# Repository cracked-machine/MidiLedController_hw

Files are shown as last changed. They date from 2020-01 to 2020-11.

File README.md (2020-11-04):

# MIDI LED Controller (HW)

Required Kicad Hardware library: https://github.com/cracked-machine/KicadLibrary

For the corresponding SW repository:
[MidiLedController_sw](https://github.com/cracked-machine/MidiLedController_sw)

## Detailed Specifications:

Power Supply: 12V @ 2A (center positive).
Total quiescent current consumption: 85mA
Voltage output per channel: 10V
Current output per channel (Nom.): 
Total current consumption (Nom.): 
Current output per channel (fault limit): 
Total current consumption (fault limit): 2A

 ## Theory of Operation

 ### Power Supply overview

 A 12V DC input supply is stepped-down to 10V. Most of this will be used to power the LEDs. This is regulated down to provide 5V @ 100mA for the status leds. Additionally 3.3V @ 20mA is provided to the microcontroller.

<p align="center">

</p>

### Output Channel overview

 MIDI Note-On commands are received and synchronised with the gating of 9 independant LED output channels.
 The brightness of all 9 channels can be adjusted simultaneously at the rear of the module.

 Fault protection monitors each output channel for short-circuit and over-current conditions.
 Fault protection is done on the _high side_ of the switch. MIDI data transmission is done on the _low side_ of the switch. i.e. the output channel anode remains at 5V (during normal operation) while the cathode is toggled by the Microcontroller GPIO.

 Individual output channel status is indicated with a tricolour LED.  See details on the Status LED sub-system below.

<p align="center">

</p>

### Output channel status LED statemachine

Each output channel has a tricolour LED. As before a _green_ LED indicates that a load is connected to the output channel and power delivery to that channel is functioning as normal. An overcurrent or short circuit event is indicated by a _red_ LED and all power is disabled from that output channel.

A _blue_ LED indicates that no load is connected to the output channel. At this point, if MIDI data is still being transferred to that channel, the status LED will alternate between green and blue, in sync with the received MIDI data. This allows testing of the MIDI data transmission without needing to connect a load to the output channel.

When the load is connected, the status LED will **always** remain solid _green_.

A _red_ power fault status such as over current or short circuit will **always** override the other status colours.

<p align="center">

</p>

### TODO

* upgrade SMPS to drop-in 3A components (TP56339, TPS54302, TPS54309). Considerations are Fsw/L1 size, Thermal Limits and cooling.
* Upgrade output series SOT23 transistor to higher currrent/thermal limit component...or to larger component (SOT223?)
* Test audio input triggering
* Additional pot control for reset delay (dual gang/ concetric pot)
* Upgrade DIP4 to DIP6

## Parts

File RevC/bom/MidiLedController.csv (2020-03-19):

Reference | Quantity | Value | Footprint | Datasheet | EbayPurchase | MouserNo | Type | LcscNo | RsComponentsNo | Unit Cost | Drawing
C1 C4 | 2 | 10u | Capacitor_SMD:C_1206_3216Metric_Pad1.42x1.75mm_HandSolder | ~ |  | 81-GRM21BC81C106KE5L | 25V | C14860 |  | 0.030736
C11 C12 | 2 | 22uF | Capacitor_SMD:C_1206_3216Metric_Pad1.42x1.75mm_HandSolder | ~ |  |  | X7R 25V | C268007 |  | 0.073018
C2 | 1 | 330nF | Capacitor_SMD:C_1206_3216Metric_Pad1.42x1.75mm_HandSolder | ~ |  |  | 25V | C73142 |  | 0.011209
C26 C5 | 2 | 100pF | Capacitor_SMD:C_0805_2012Metric_Pad1.15x1.40mm_HandSolder | ~ |  |  | N/A | C152892 |  | 0.008889
C3 | 1 | 100nF | Capacitor_SMD:C_1206_3216Metric_Pad1.42x1.75mm_HandSolder | ~ |  |  | 10V | C94108 |  | 0.005
C30 | 1 | 100n | Resistor_SMD:R_0805_2012Metric_Pad1.15x1.40mm_HandSolder | ~ |  |  | 10V | C94108 |  | 0.005
C32 | 1 | 4.7u | Capacitor_SMD:C_0805_2012Metric_Pad1.15x1.40mm_HandSolder | ~ |  |  | N/A | C87998 |  | 0.020584
C33 | 1 | 10n | Capacitor_SMD:C_0805_2012Metric_Pad1.15x1.40mm_HandSolder | ~ |  |  | N/A | C107135 |  | 0.009327
C34 C29 C31 | 3 | 1u | Capacitor_SMD:C_0805_2012Metric_Pad1.15x1.40mm_HandSolder | ~ |  |  | N/A | C376927 |  | 0.009595
C6 C28 | 2 | 100n | Capacitor_SMD:C_0805_2012Metric_Pad1.15x1.40mm_HandSolder | ~ |  |  | N/A | C94108 |  | 0.005
C8 | 1 | 180pF | Resistor_SMD:R_0805_2012Metric_Pad1.15x1.40mm_HandSolder | ~ |  |  | N/A | C152881 |  | 0.003814
C9 | 1 | 100nF | Resistor_SMD:R_0805_2012Metric_Pad1.15x1.40mm_HandSolder | ~ |  |  | X7R | C94108 |  | 0.005
D13 | 1 | BZT52C5V1 | Diode_SMD:D_SOD-123 | https://diotec.com/tl_files/diotec/files/pdf/datasheets/bzt52b2v4.pdf |  |  | Vz=5.1V | C353516 |  | 0.005325
D2 | 1 | 1N4148 | Diode_SMD:D_SOD-323_HandSoldering | ~ |  |  | N/A | C110221 |  | 0.004722
D_STATUS1 D_STATUS_2 D_STATUS_3 D_STATUS_4 D_STATUS_5 D_STATUS_6 D_STATUS_7 D_STATUS_8 D_STATUS_9 | 9 | LED_RAGB | LED_THT:LED_D5.0mm-4_RGB_Wide_Pins | ~ | TRUE |  |  |  |  | 0.11
J1 | 1 | Molex 2Way KK254 | Connector_PinHeader_2.54mm:PinHeader_1x05_P2.54mm_Vertical | ~ | TRUE
J12 | 1 | Barrel_Jack | Connector_BarrelJack:BarrelJack_Horizontal | ~ | TRUE |  |  |  |  | 0.04
J_AUX1 | 1 | Conn_01x04 | Connector_PinHeader_2.54mm:PinHeader_1x04_P2.54mm_Vertical | ~ | TRUE
J_MIDI_IN1 | 1 | DIN-5 | custom_sockets:RS_5P180_DIN5_SOCKET_WSHIELD | https://docs-emea.rs-online.com/webdocs/1579/0900766b81579be1.pdf | TRUE |  |  |  |  | 0.23 | https://docs-emea.rs-online.com/webdocs/1579/0900766b81579be0.pdf
J_OUT1 J_OUT2 J_OUT3 J_OUT4 J_OUT5 J_OUT6 J_OUT7 J_OUT8 J_OUT9 | 9 | Barrel_Jack_Switch | Connector_BarrelJack:BarrelJack_Horizontal | ~ | TRUE |  |  |  |  | 0.04
L2 | 1 | 4.7uH | Inductor_SMD:L_Taiyo-Yuden_NR-80xx_HandSoldering | https://www.mouser.co.uk/datasheet/2/396/wound04_e-1290968.pdf |  |  | 3A | C266428 |  | 0.054256
Q1 Q2 Q3 Q4 Q5 Q6 Q7 Q8 Q9 Q10 Q11 Q12 Q13 Q14 Q15 Q16 Q17 Q18 | 18 | MBT3946DW1T1 | Package_TO_SOT_SMD:SOT-363_SC-70-6 | http://www.onsemi.com/pub_link/Collateral/MBT3946DW1T1-D.PDF |  |  |  |  | 791-6078 | 0.045
Q21 | 1 | HX2301A | Package_TO_SOT_SMD:SOT-23 | https://datasheet.lcsc.com/szlcsc/1912111437_HX-hengjiaxing-HX2301A_C296298.pdf |  |  | VGS=+/-12V | C296298 |  | 0.01
QLOAD1 QLOAD2 QLOAD3 QLOAD4 QLOAD6 QLOAD7 QLOAD8 QLOAD9 QLOAD5 | 9 | MMBT3904 | Package_TO_SOT_SMD:SOT-23 | https://datasheet.lcsc.com/szlcsc/1810202112_Guangdong-Hottech-MMBT3904_C181119.pdf |  |  |  | C20526 |  | 0.009
R1 R3 R2 R6 R5 R8 R7 R11 R10 R14 R12 R18 R17 R20 R19 R22 R21 R24 R23 | 19 | 10K | Resistor_SMD:R_0805_2012Metric_Pad1.15x1.40mm_HandSolder | ~ |  |  | N/A | C115295 |  | 0.001482
R119 R120 R121 R122 | 4 | 1K | Resistor_SMD:R_0805_2012Metric_Pad1.15x1.40mm_HandSolder | ~ |  |  | N/A | C25623 |  | 0.001
R15 R13 | 2 | 100K | Resistor_SMD:R_0805_2012Metric_Pad1.15x1.40mm_HandSolder | ~ |  |  | N/A | C118844 |  | 0.001534
R16 | 1 | 6K2 | Resistor_SMD:R_0805_2012Metric_Pad1.15x1.40mm_HandSolder | ~ |  | 71-CRCW080510K0FKEAC | N/A |  |  | 0.046
R4 | 1 | 220R | Resistor_SMD:R_0805_2012Metric_Pad1.15x1.40mm_HandSolder | ~ |  | 71-CRCW0805220RFKEAC | N/A |  |  | 0.046
R74 R25 | 2 | 100R | Resistor_SMD:R_0805_2012Metric_Pad1.15x1.40mm_HandSolder | ~ |  |  | N/A | C106949 |  | 0.001048
R86 | 1 | 100K | Resistor_SMD:R_1206_3216Metric_Pad1.42x1.75mm_HandSolder | ~ |  |  | N/A | C118844 |  | 0.001534
R9 | 1 | 4K7 | Resistor_SMD:R_0805_2012Metric_Pad1.15x1.40mm_HandSolder | ~ |  | 279-CRGP0805F270R | N/A |  |  | 0.13
RV1 | 1 | PTH901 | PTH901:PTH901 | https://www.bourns.com/docs/product-datasheets/PTH90.pdf |  | 652-PTH901-030S-103B | PTH901-030S-103B1 |  |  | 1.30
SW1 | 1 | SW_DIP_x04 | Button_Switch_THT:SW_DIP_SPSTx04_Slide_6.7x11.72mm_W7.62mm_P2.54mm_LowProfile | ~ | TRUE |  |  |  |  | 0.07
SW2 | 1 | SW_SPST | Button_Switch_THT:SW_Tactile_SPST_Angled_PTS645Vx31-2LFS | ~ | TRUE |  |  |  |  | 0.06
TP4 TP1 TP7 TP50 TP46 TP44 TP42 TP19 TP3 TP28 TP31 TP30 TP2 | 13 | TestPoint | TestPoint:TestPoint_Pad_1.0x1.0mm | ~ |  |  |  |  |  | ———
U1 U2 U3 U4 U5 U6 U7 U8 U9 U10 U11 U12 U13 U14 U15 U16 U17 U18 | 18 | RAx4_4 1K | Resistor_SMD:R_Array_Convex_4x0603 | https://datasheet.lcsc.com/szlcsc/1912111437_HX-hengjiaxing-HX2301A_C296298.pdf |  |  | N/A | C396839 |  | 0.006
U20 | 1 | STM32F051K8Tx | Package_QFP:LQFP-32_7x7mm_P0.8mm | http://www.st.com/st-web-ui/static/active/en/resource/technical/document/datasheet/DM00039193.pdf |  | 511-STM32F051K8T6 |  |  |  | 1.81
U21 | 1 | 6N135S | Package_DIP:DIP-8_W8.89mm_SMDSocket_LongPads | https://optoelectronics.liteon.com/upload/download/DS70-2008-0032/6N135-L%206N136-L%20series.pdf |  | 859-6N135S |  |  |  | 0.42
U22 | 1 | TPS54202DDCR | Package_TO_SOT_SMD:SOT-23-6 | http://www.ti.com/lit/ds/symlink/tps54202.pdf |  |  |  | C191884 |  | 0.14
U23 | 1 | L7805 | Package_TO_SOT_SMD:TO-263-2 | http://www.st.com/content/ccc/resource/technical/document/datasheet/41/4f/b3/b0/12/d4/47/88/CD00000444.pdf/files/CD00000444.pdf/jcr:content/translations/en.CD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 |  |  |  | C15077 |  | 0.17
U24 | 1 | MCP1754ST-3302E/CB | Package_TO_SOT_SMD:SOT-23 | http://ww1.microchip.com/downloads/en/DeviceDoc/20002276C.pdf |  | 579-MCP1754T-3302ECB |  |  |  | 0.26
U25 | 1 | NCP51460SN33T1G | Package_TO_SOT_SMD:SOT-23 | https://www.onsemi.com/pub/Collateral/NCP51460-D.PDF |  | 863-NCP51460SN33T1G | Voltage Reference |  |  | 0.34
U_LOAD1 U_LOAD2 U_LOAD3 U_LOAD4 U_LOAD5 U_LOAD6 U_LOAD7 U_LOAD8 U_LOAD9 | 9 | NCV8450 | Package_TO_SOT_SMD:SOT-223-3_TabPin2 | https://datasheet.lcsc.com/szlcsc/1912111437_ON-Semiconductor-NCV8450ASTT3G_C100028.pdf |  |  |  | C100028 |  | 0.26
TOTAL |  |  |  |  |  |  |  |  |  | 5.800073

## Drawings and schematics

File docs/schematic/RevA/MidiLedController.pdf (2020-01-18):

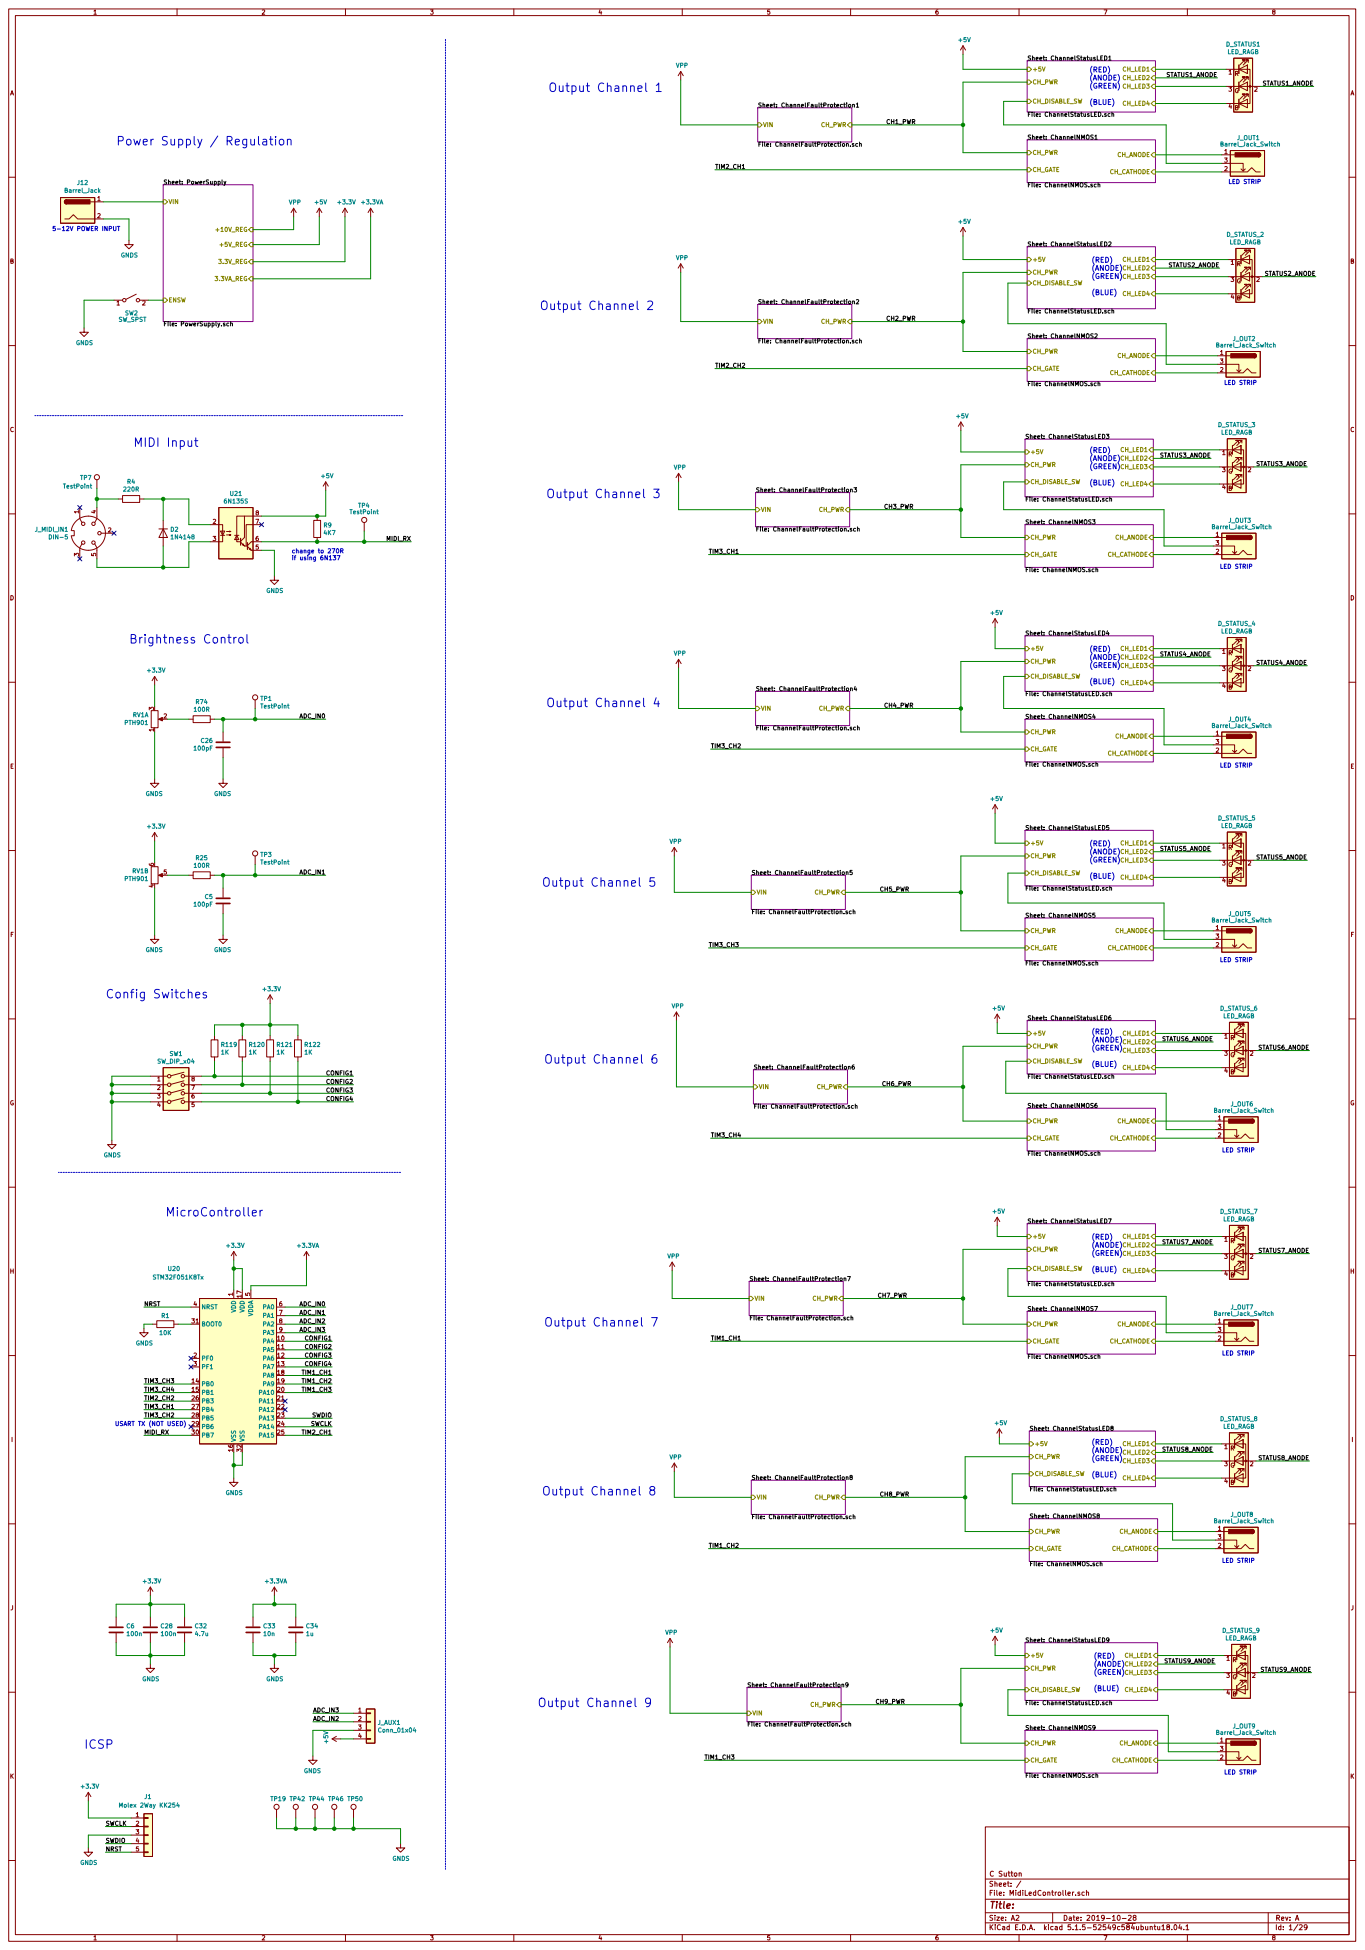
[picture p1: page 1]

File: PowerSupply.sch VIN

Sheet: ChannelNMOS1 File: ChannelNMOS.sch CH_PWR

Sheet: ChannelNMOS2 File: ChannelNMOS.sch CH_PWR

Sheet: ChannelNMOS3 File: ChannelNMOS.sch CH_PWR

Sheet: ChannelNMOS4 File: ChannelNMOS.sch CH_PWR

STATUS5_ANODE Output Channel 6
LED STRIP Output Channel 5

Sheet: ChannelNMOS5 File: ChannelNMOS.sch CH_PWR

Sheet: ChannelNMOS6 File: ChannelNMOS.sch CH_PWR

1 PA4 10 PA5 11 PA6 12 PA7 13 PB0 14 PB1 15 VSS 16 VDD 17 PA8 18 PA9 19 PF0 2 PA10 20 PA11 21 PA12 22 PA13 23 PA14 24 PA15 25 PB3 26 PB4 27 PB5 28 PB6 29 PF1 3 PB7 30 BOOT0 31 VSS 32 NRST 4 VDDA
ADC_IN3 ADC_IN2 ADC_IN1 ADC_IN3 ADC_IN2

Sheet: ChannelNMOS7 File: ChannelNMOS.sch CH_PWR

USART TX (NOT USED)

Sheet: ChannelNMOS8 File: ChannelNMOS.sch CH_PWR

Sheet: ChannelFaultProtection9 File: ChannelFaultProtection.sch CH_PWR

Sheet: ChannelNMOS9 File: ChannelNMOS.sch CH_PWR

Id: 1/29 Title: File: MidiLedController.sch Sheet: / C Sutton

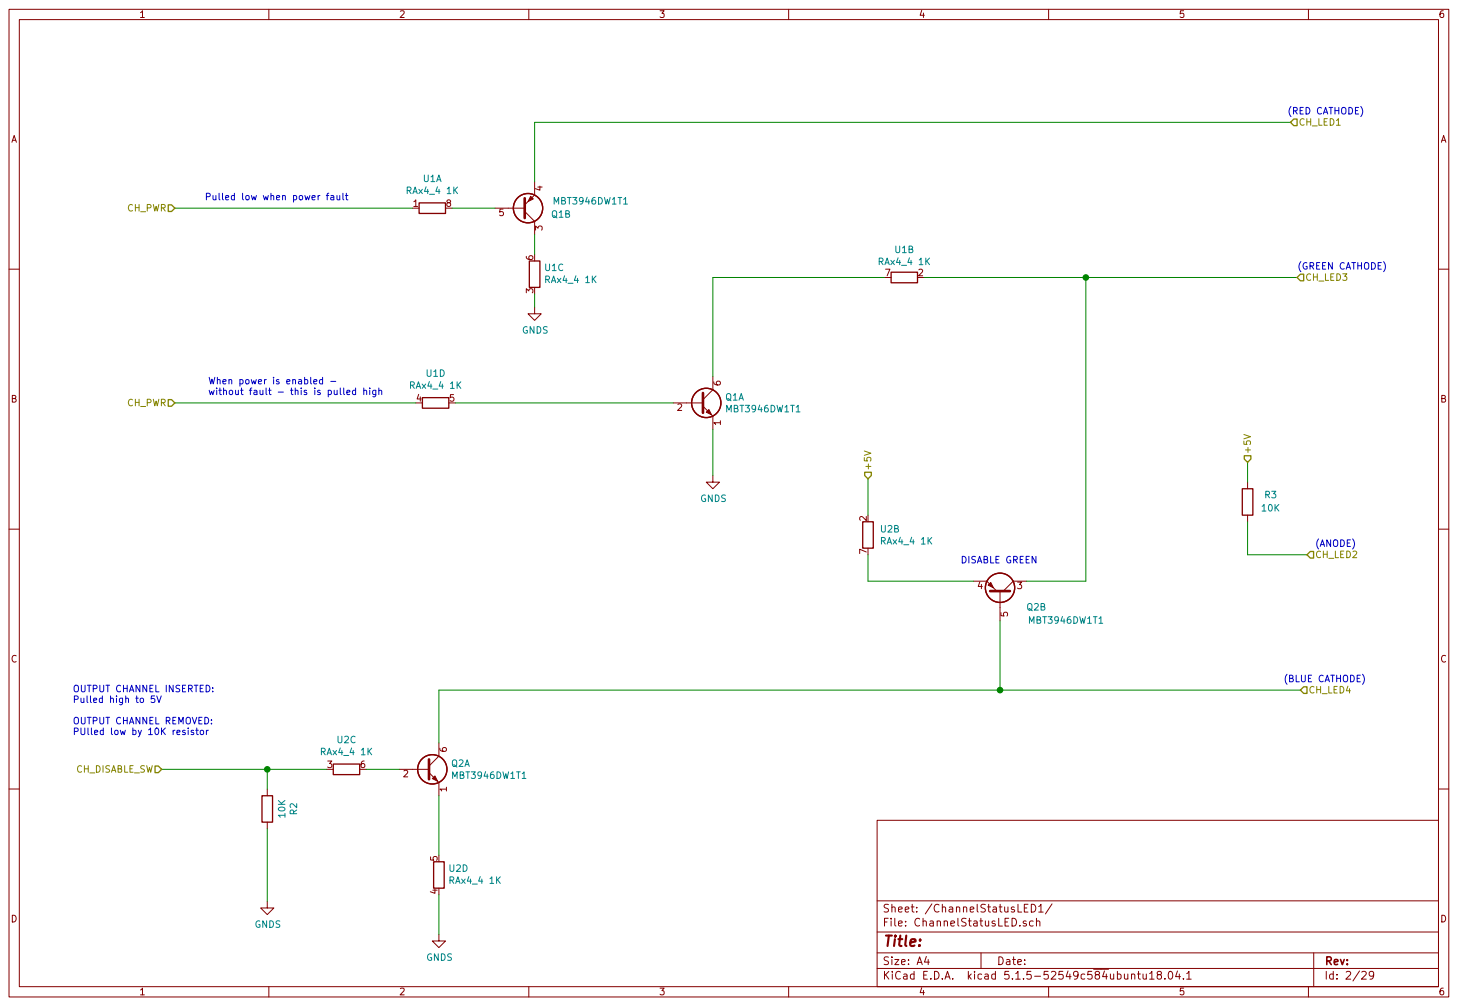
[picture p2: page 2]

Pulled low when power fault

(GREEN CATHODE) OUTPUT CHANNEL INSERTED: Pulled high to 5V OUTPUT CHANNEL REMOVED: PUlled low by 10K resistor

When power is enabled -
without fault - this is pulled high

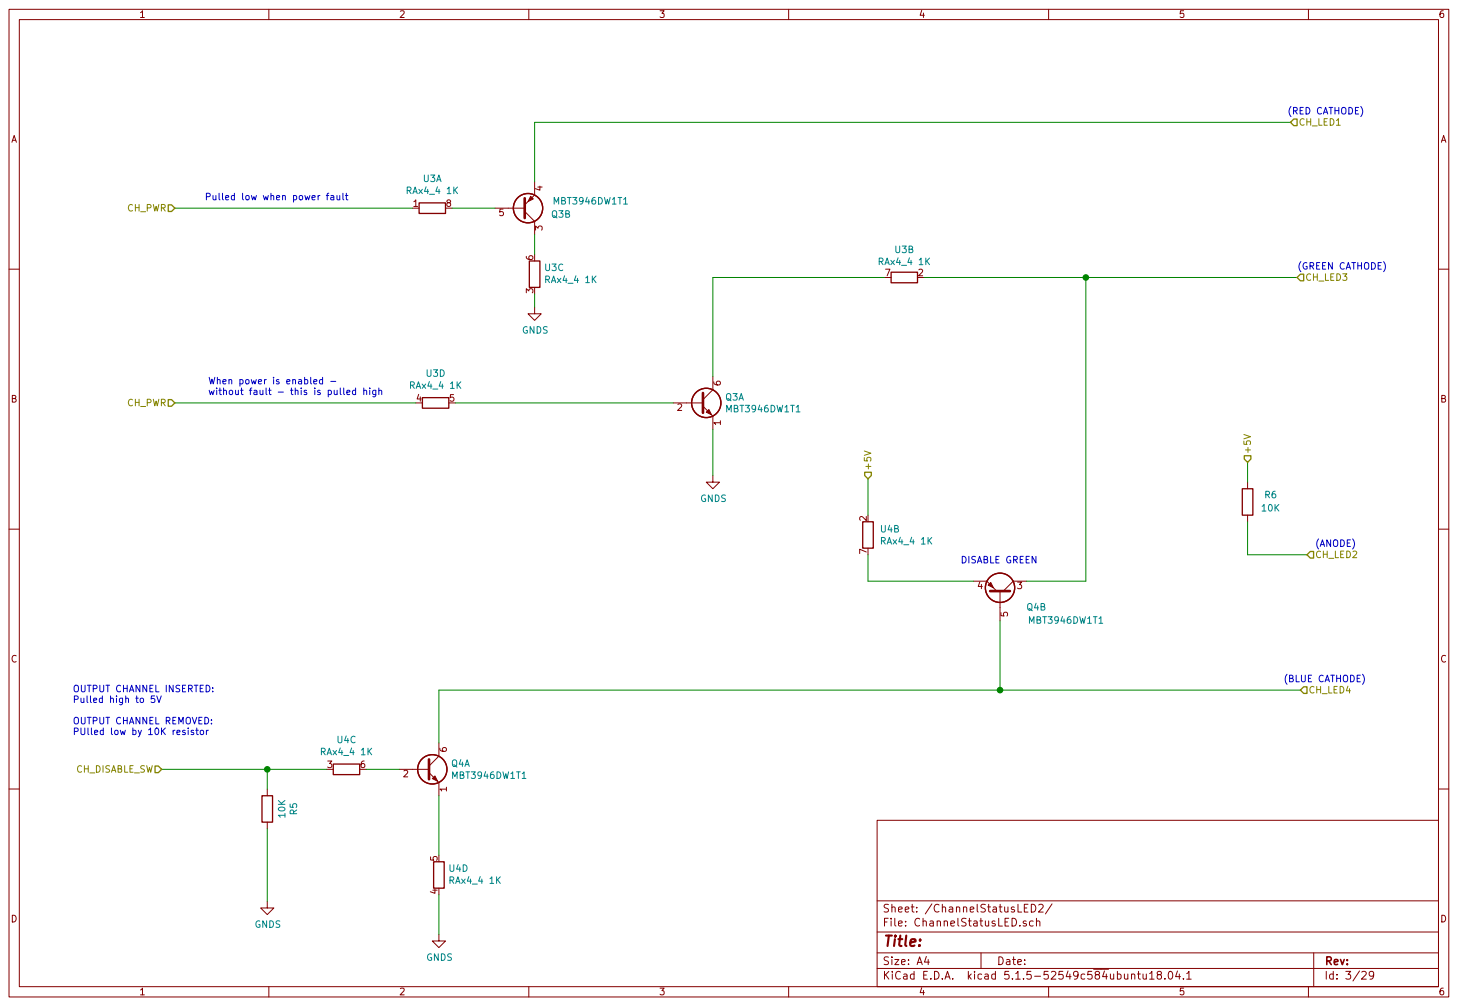
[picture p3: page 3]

Pulled low when power fault

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

When power is enabled -
without fault - this is pulled high

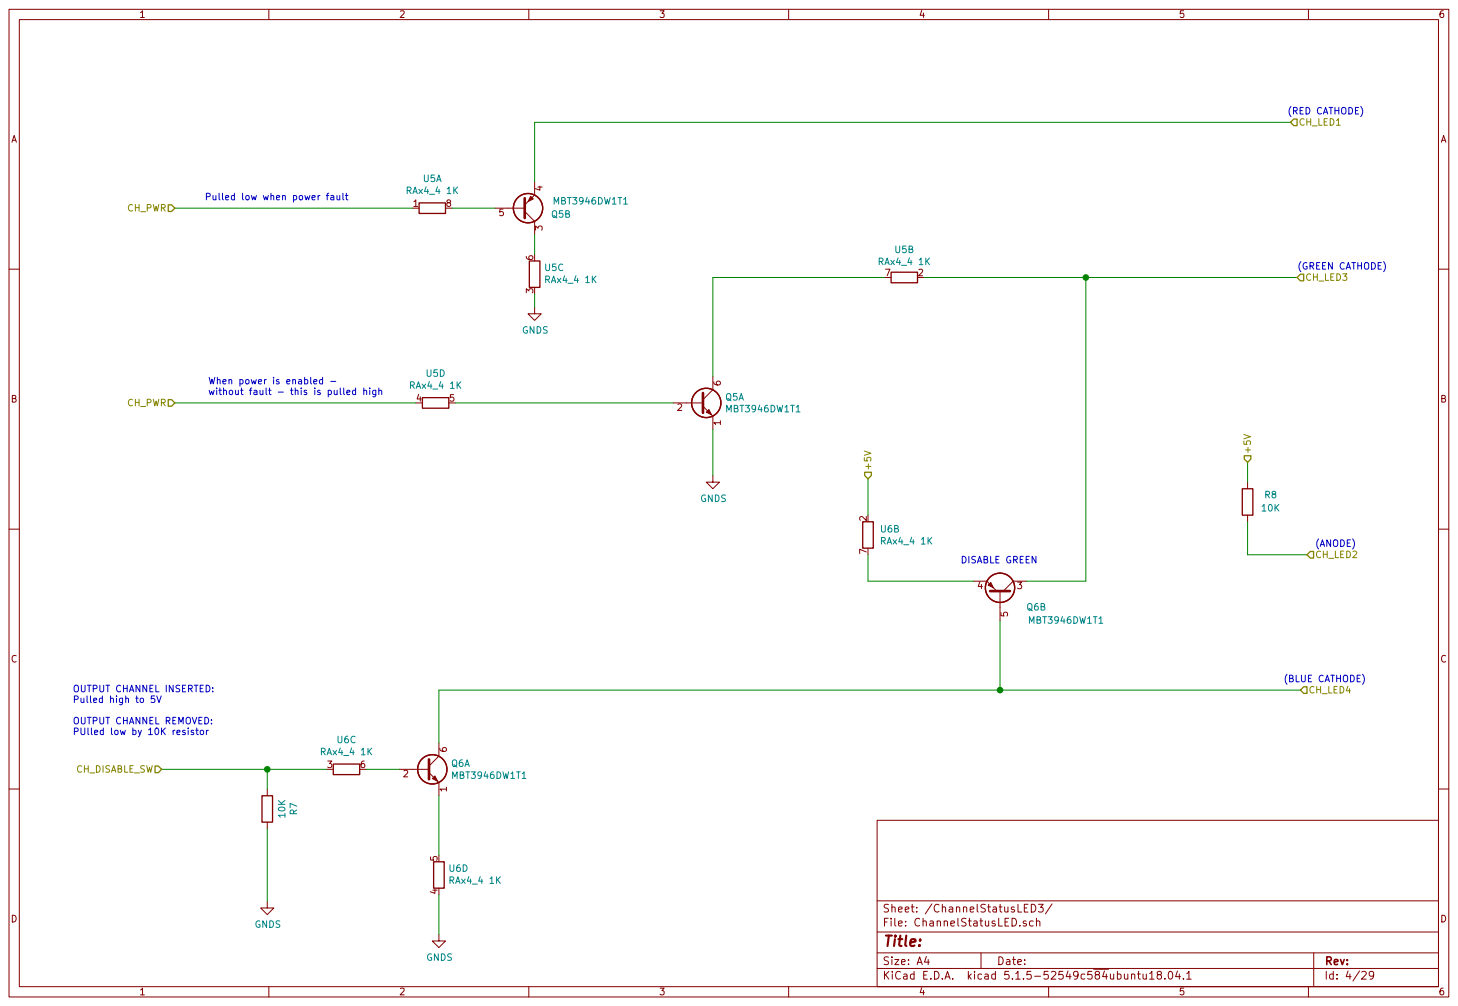
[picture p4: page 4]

Pulled low when power fault

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

When power is enabled -
without fault - this is pulled high

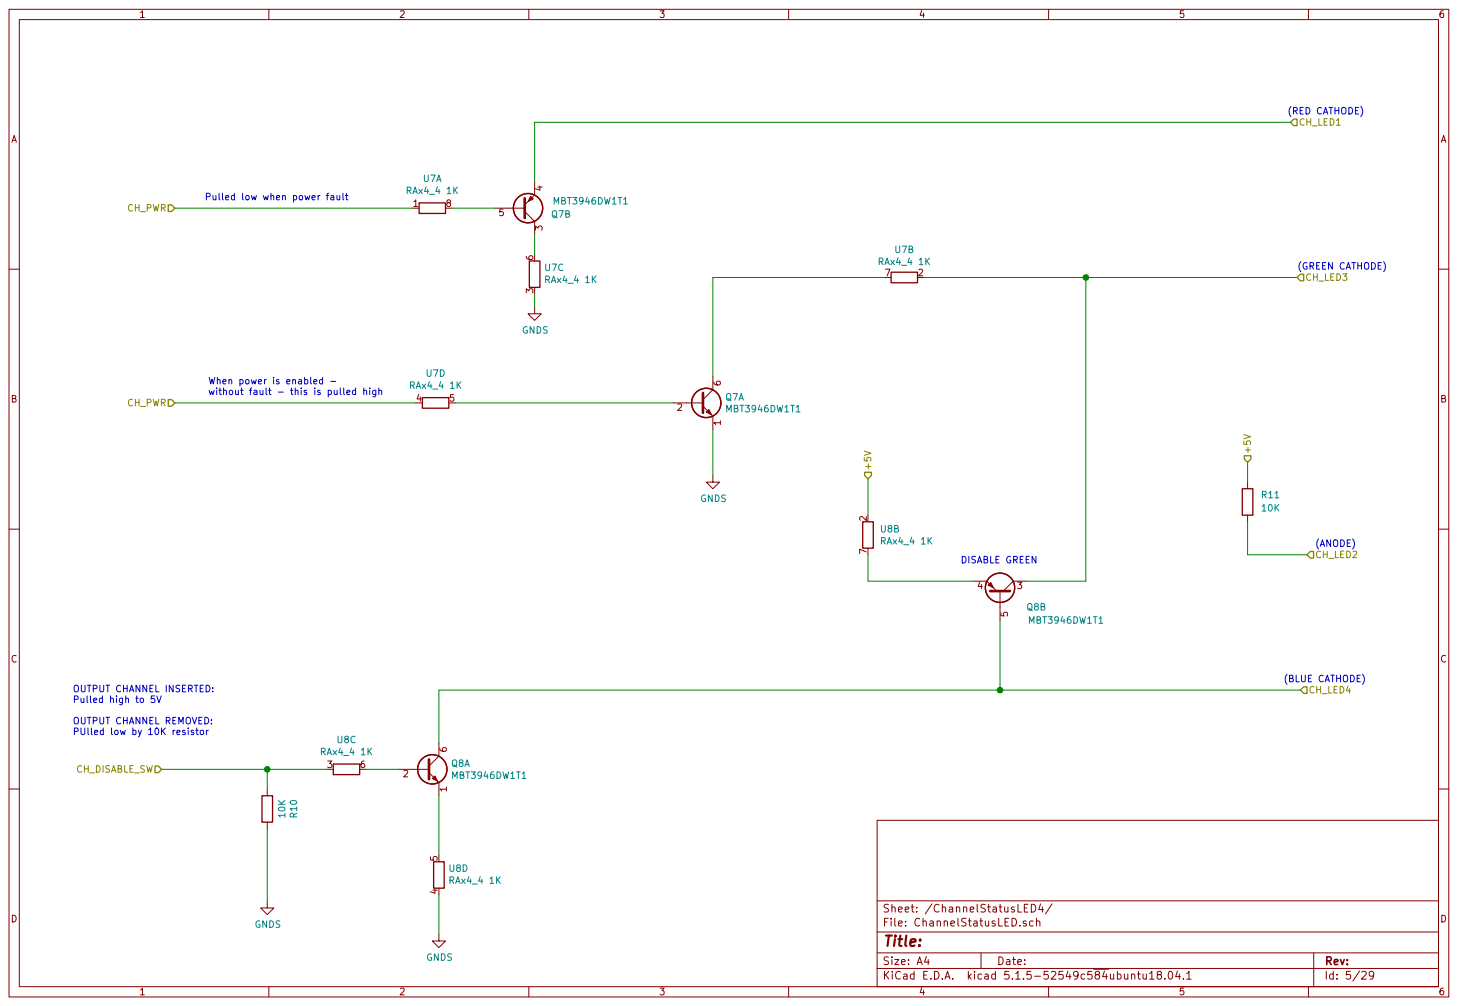
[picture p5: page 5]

Pulled low when power fault

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

When power is enabled -
without fault - this is pulled high

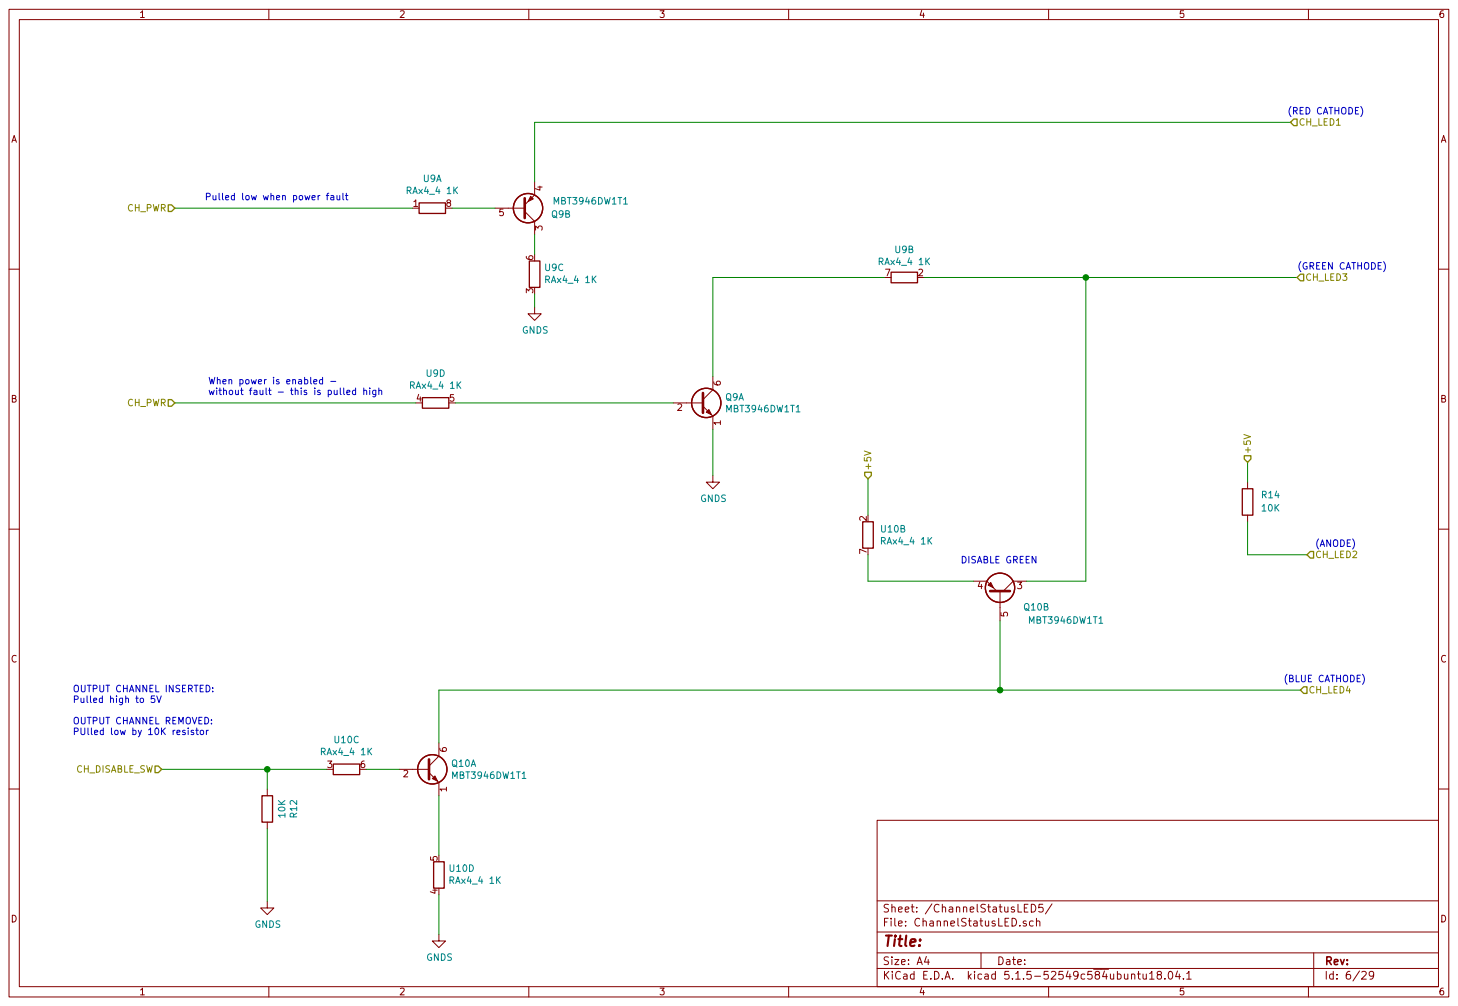
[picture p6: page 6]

Pulled low when power fault

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

When power is enabled -
without fault - this is pulled high

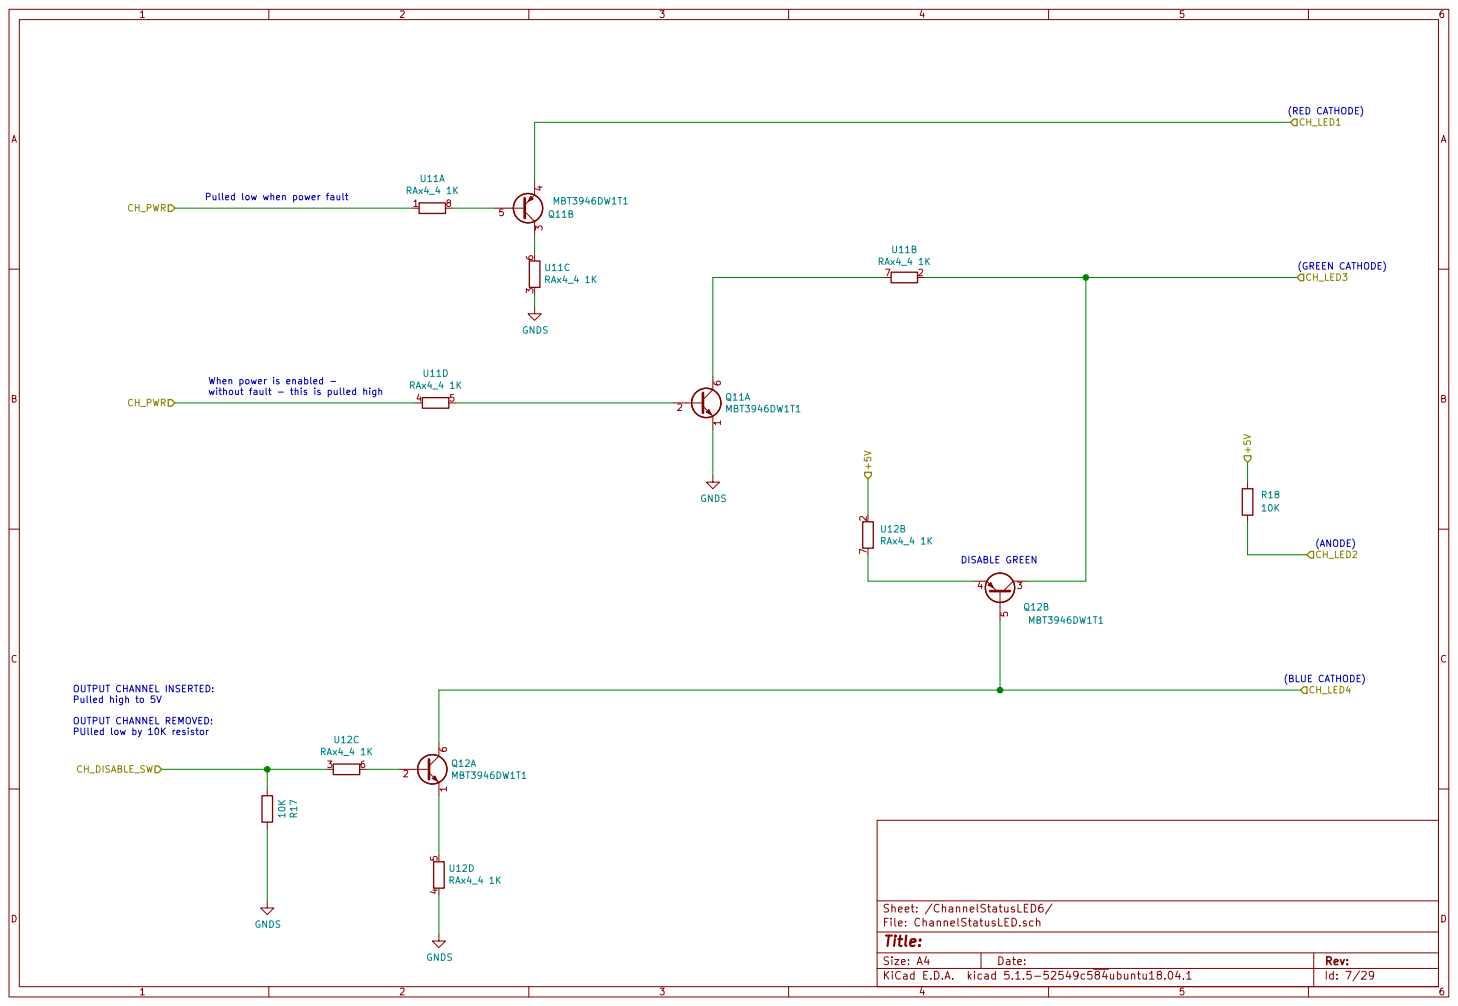
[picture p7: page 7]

Pulled low when power fault

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

When power is enabled -
without fault - this is pulled high

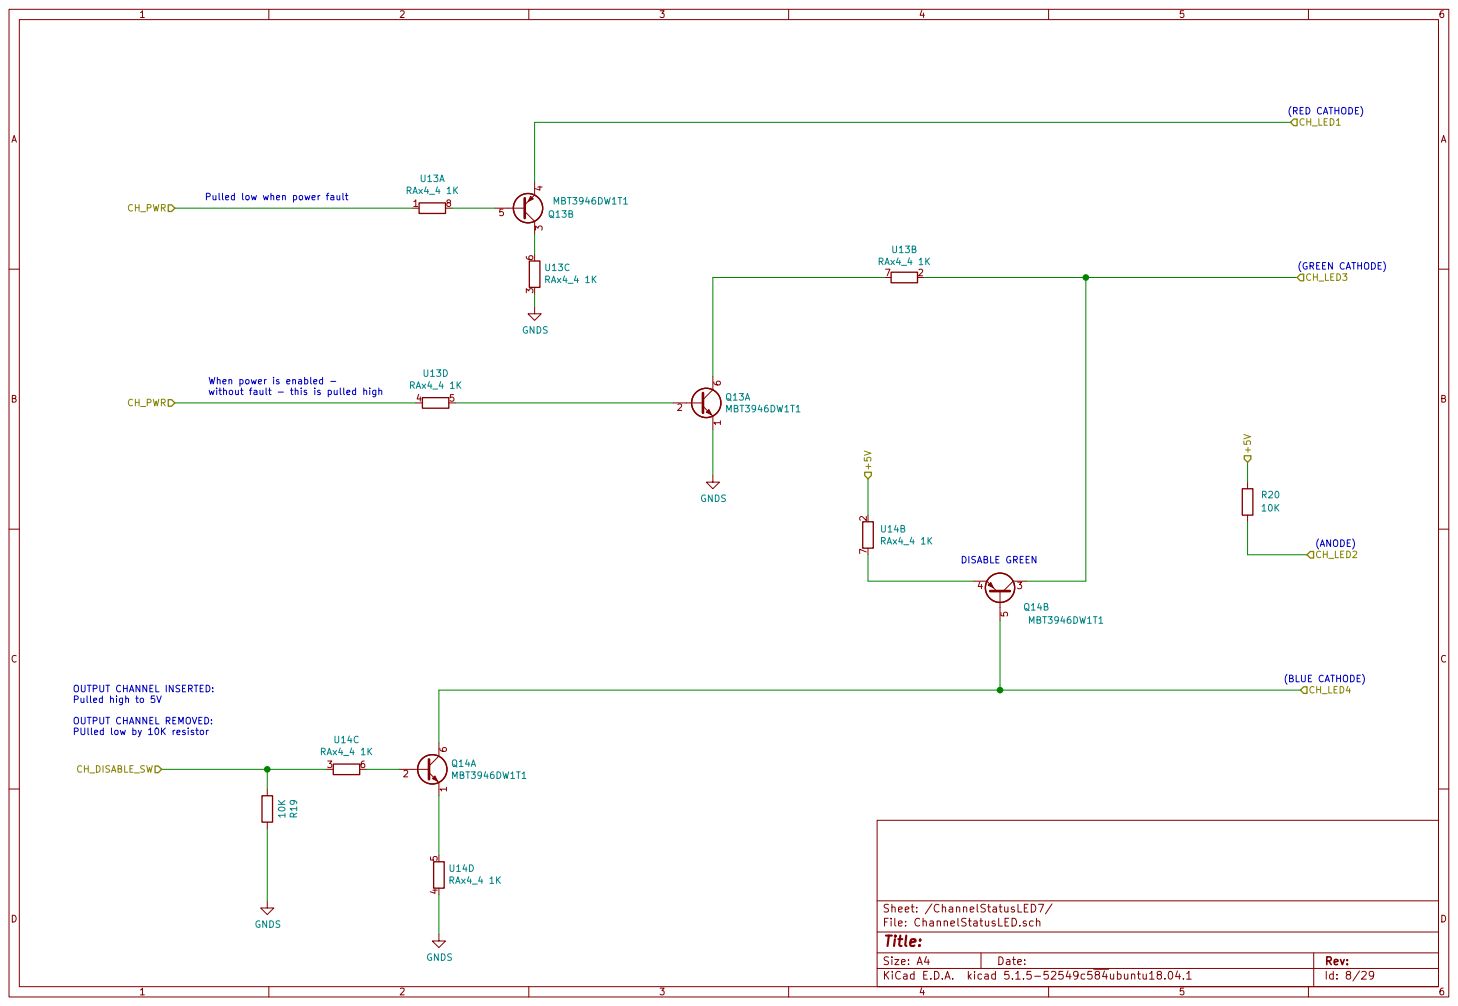
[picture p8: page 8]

Pulled low when power fault

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

When power is enabled -
without fault - this is pulled high

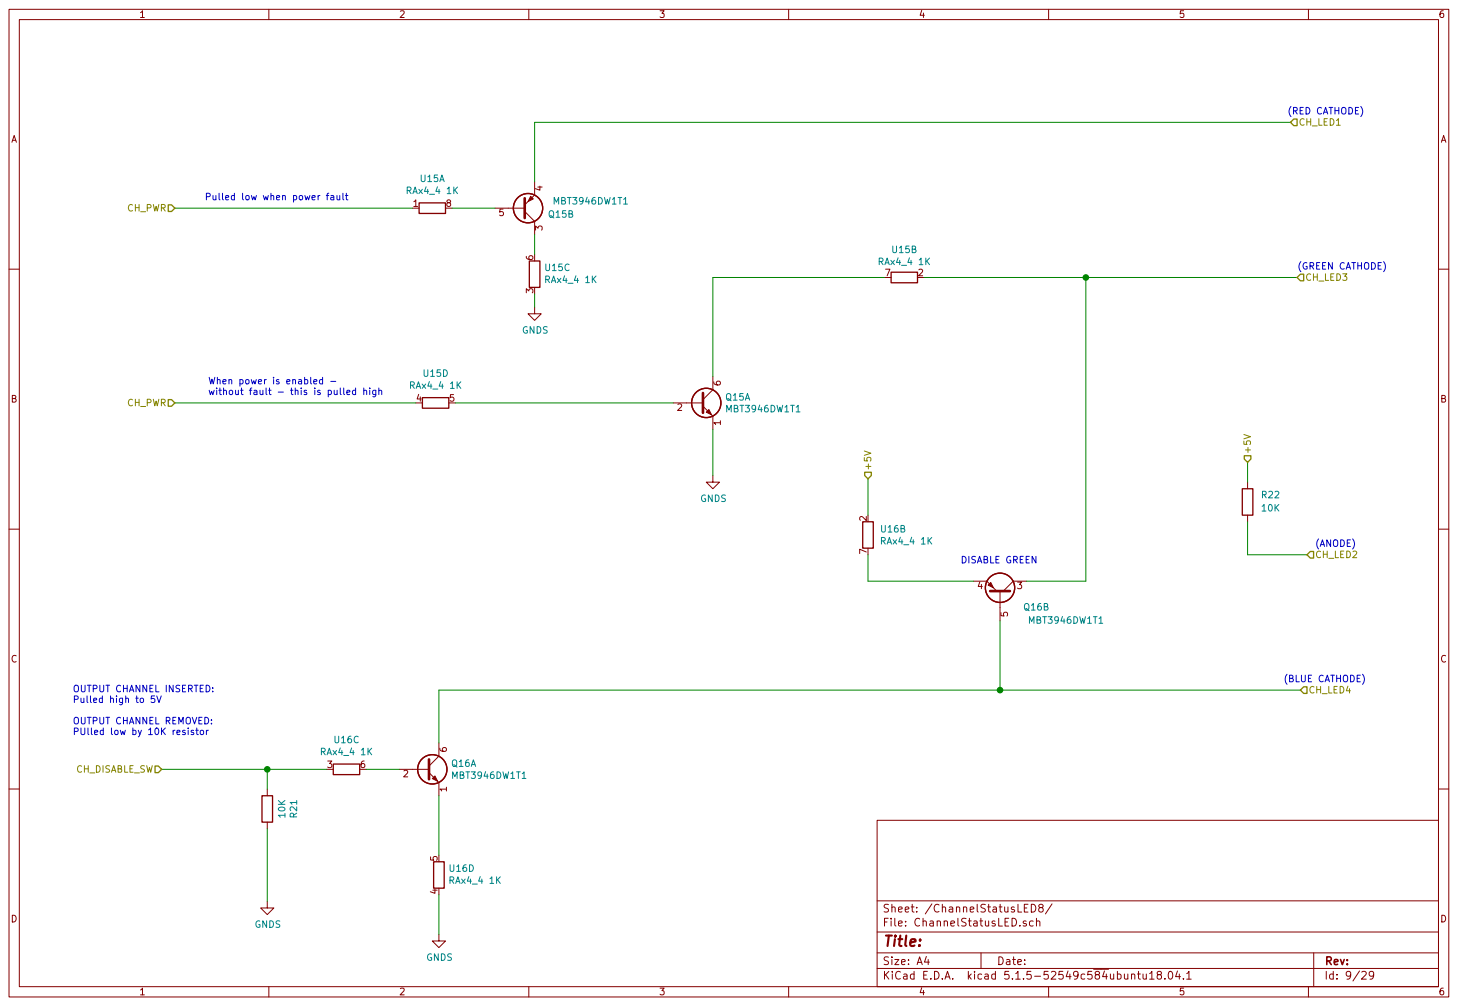
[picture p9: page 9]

Pulled low when power fault

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

When power is enabled -
without fault - this is pulled high

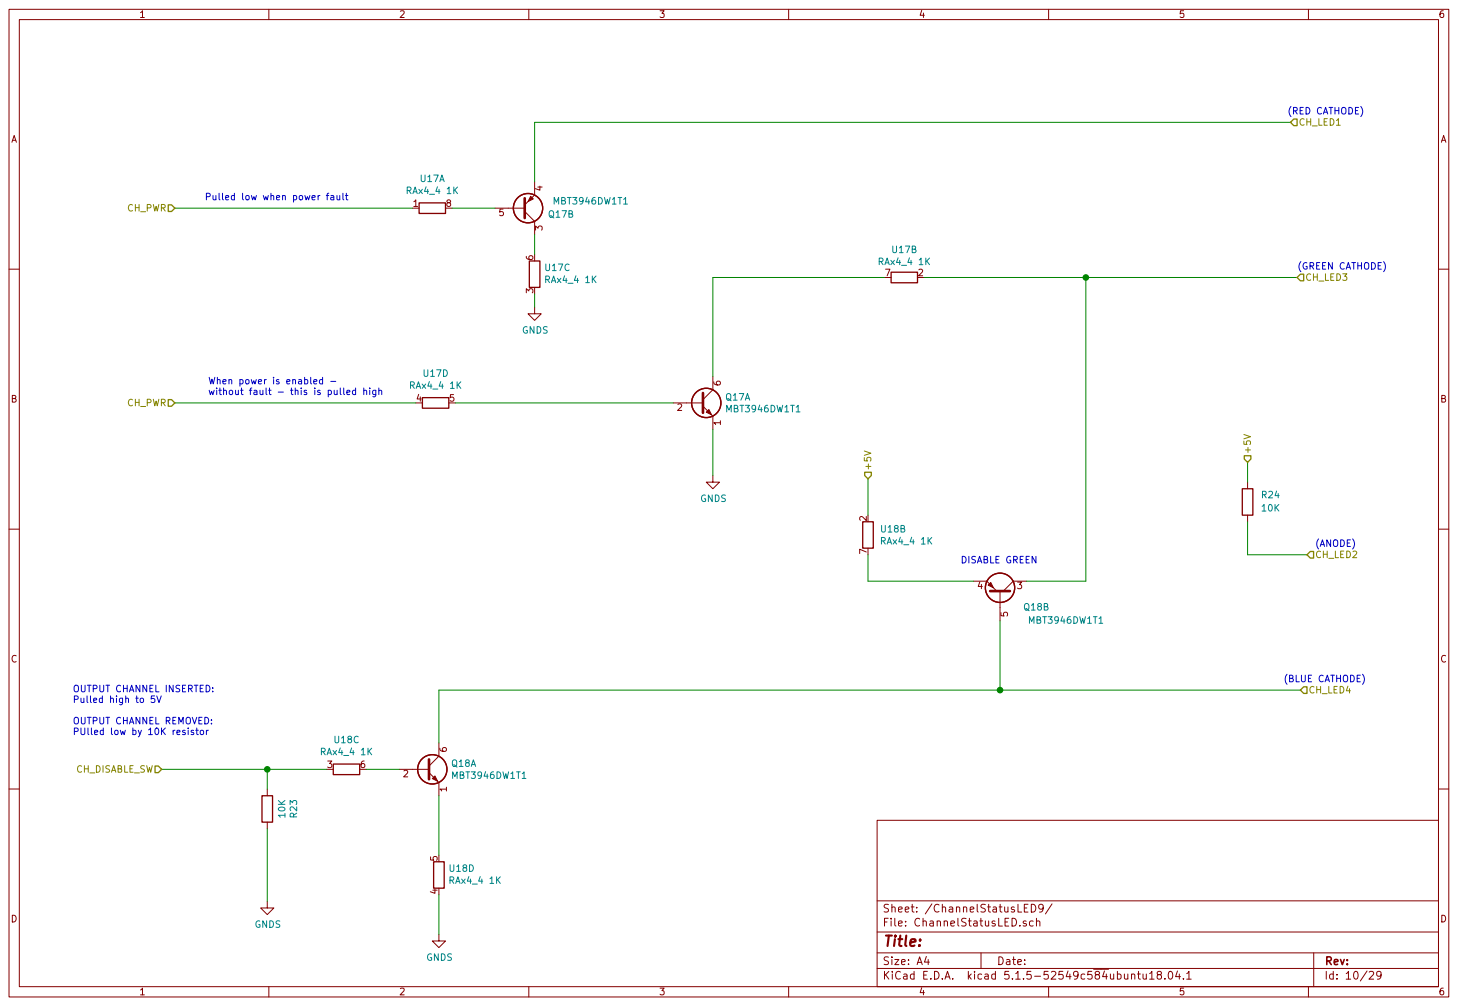
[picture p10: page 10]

Pulled low when power fault

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

When power is enabled -
without fault - this is pulled high

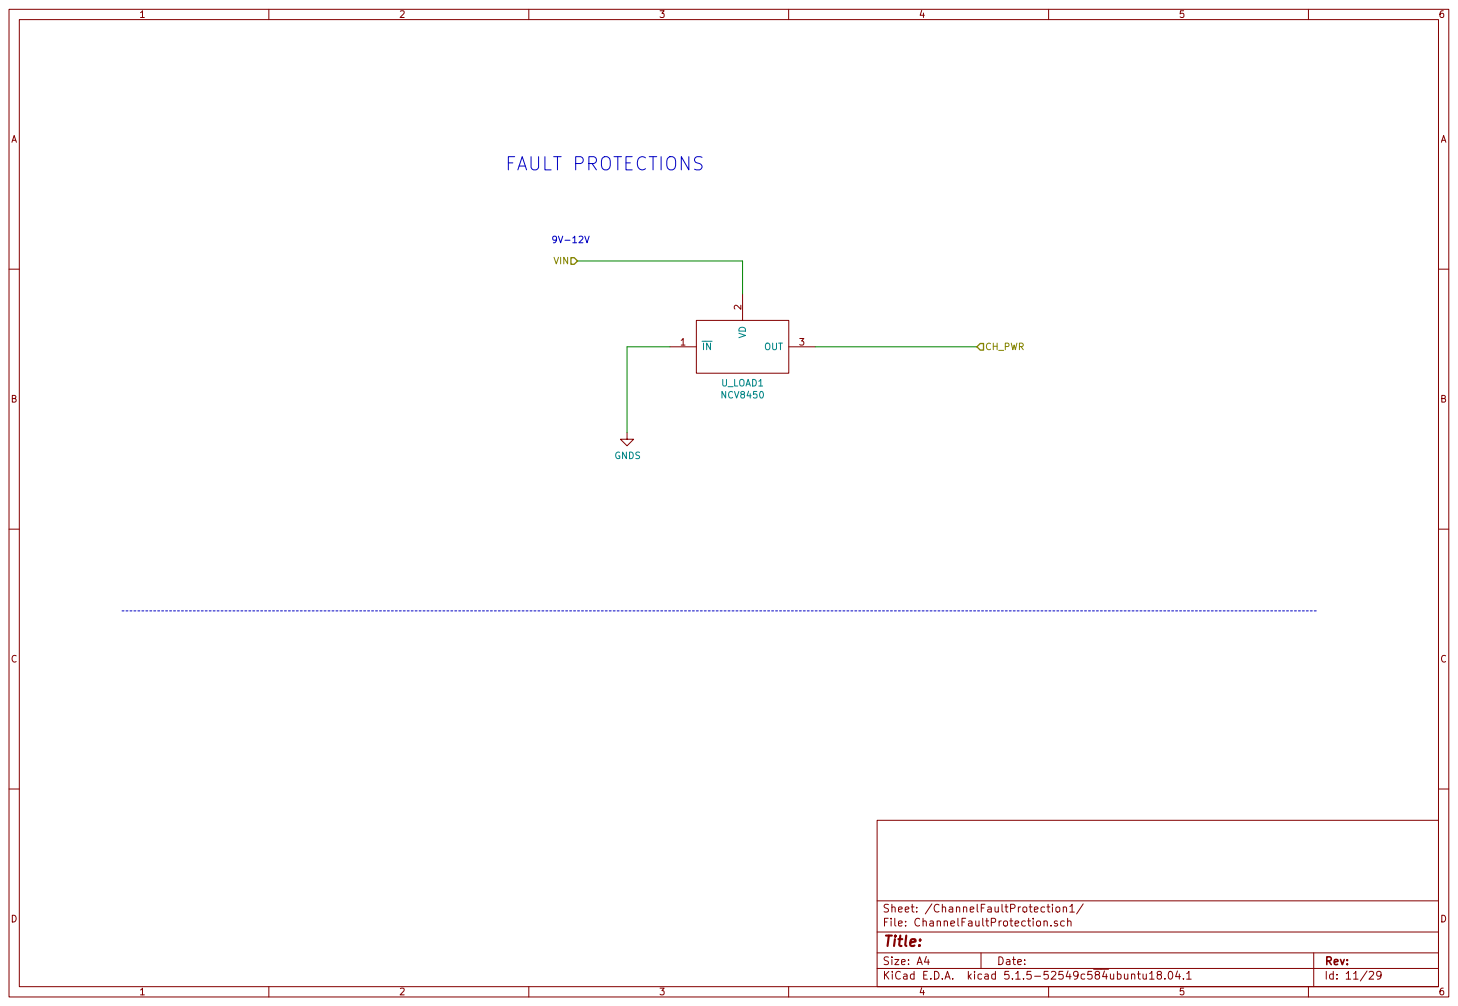
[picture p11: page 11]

Id: 11/29 Title: File: ChannelFaultProtection.sch Sheet: /ChannelFaultProtection1/

Id: 12/29 Title: File: ChannelFaultProtection.sch Sheet: /ChannelFaultProtection2/

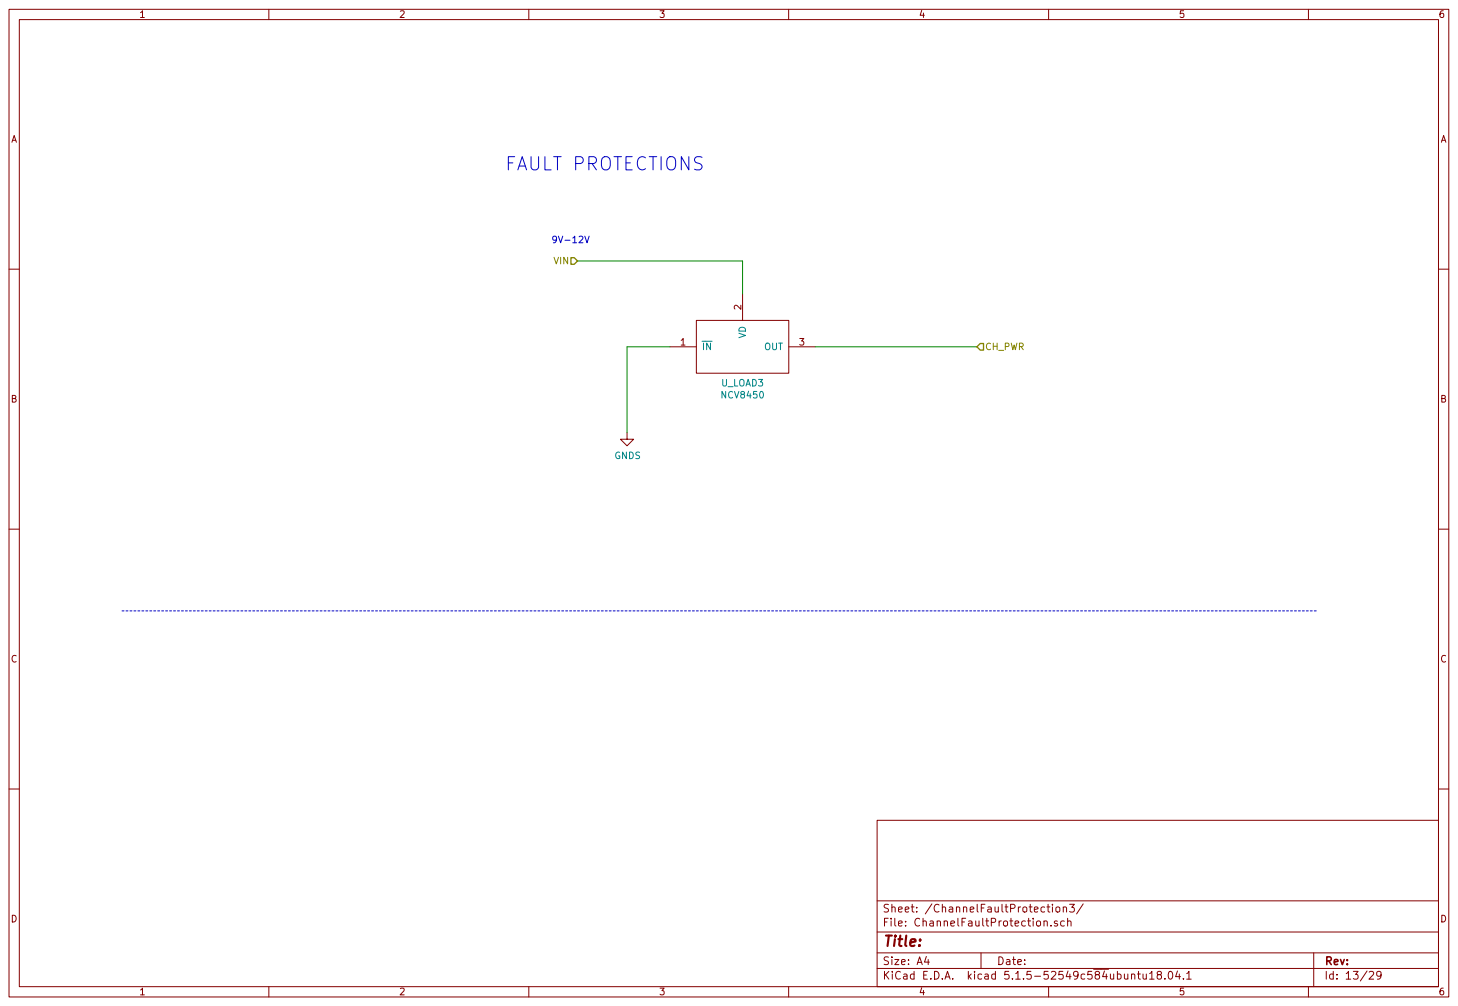
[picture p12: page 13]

Id: 13/29 Title: File: ChannelFaultProtection.sch Sheet: /ChannelFaultProtection3/


Id: 14/29 Title: File: ChannelFaultProtection.sch Sheet: /ChannelFaultProtection4/


Id: 15/29 Title: File: ChannelFaultProtection.sch Sheet: /ChannelFaultProtection5/

Id: 16/29 Title: File: ChannelFaultProtection.sch Sheet: /ChannelFaultProtection6/


Id: 17/29 Title: File: ChannelFaultProtection.sch Sheet: /ChannelFaultProtection7/


Id: 18/29 Title: File: ChannelFaultProtection.sch Sheet: /ChannelFaultProtection8/

Id: 19/29 Title: File: ChannelFaultProtection.sch Sheet: /ChannelFaultProtection9/


Input signal at base will pull
CH_CATHODE down to ground

Id: 20/29 Title: File: ChannelNMOS.sch Sheet: /ChannelNMOS1/ GNDS


Input signal at base will pull
CH_CATHODE down to ground

Id: 21/29 Title: File: ChannelNMOS.sch Sheet: /ChannelNMOS2/ GNDS


Input signal at base will pull
CH_CATHODE down to ground

Id: 22/29 Title: File: ChannelNMOS.sch Sheet: /ChannelNMOS3/ GNDS

Input signal at base will pull
CH_CATHODE down to ground

Id: 23/29 Title: File: ChannelNMOS.sch Sheet: /ChannelNMOS4/ GNDS

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

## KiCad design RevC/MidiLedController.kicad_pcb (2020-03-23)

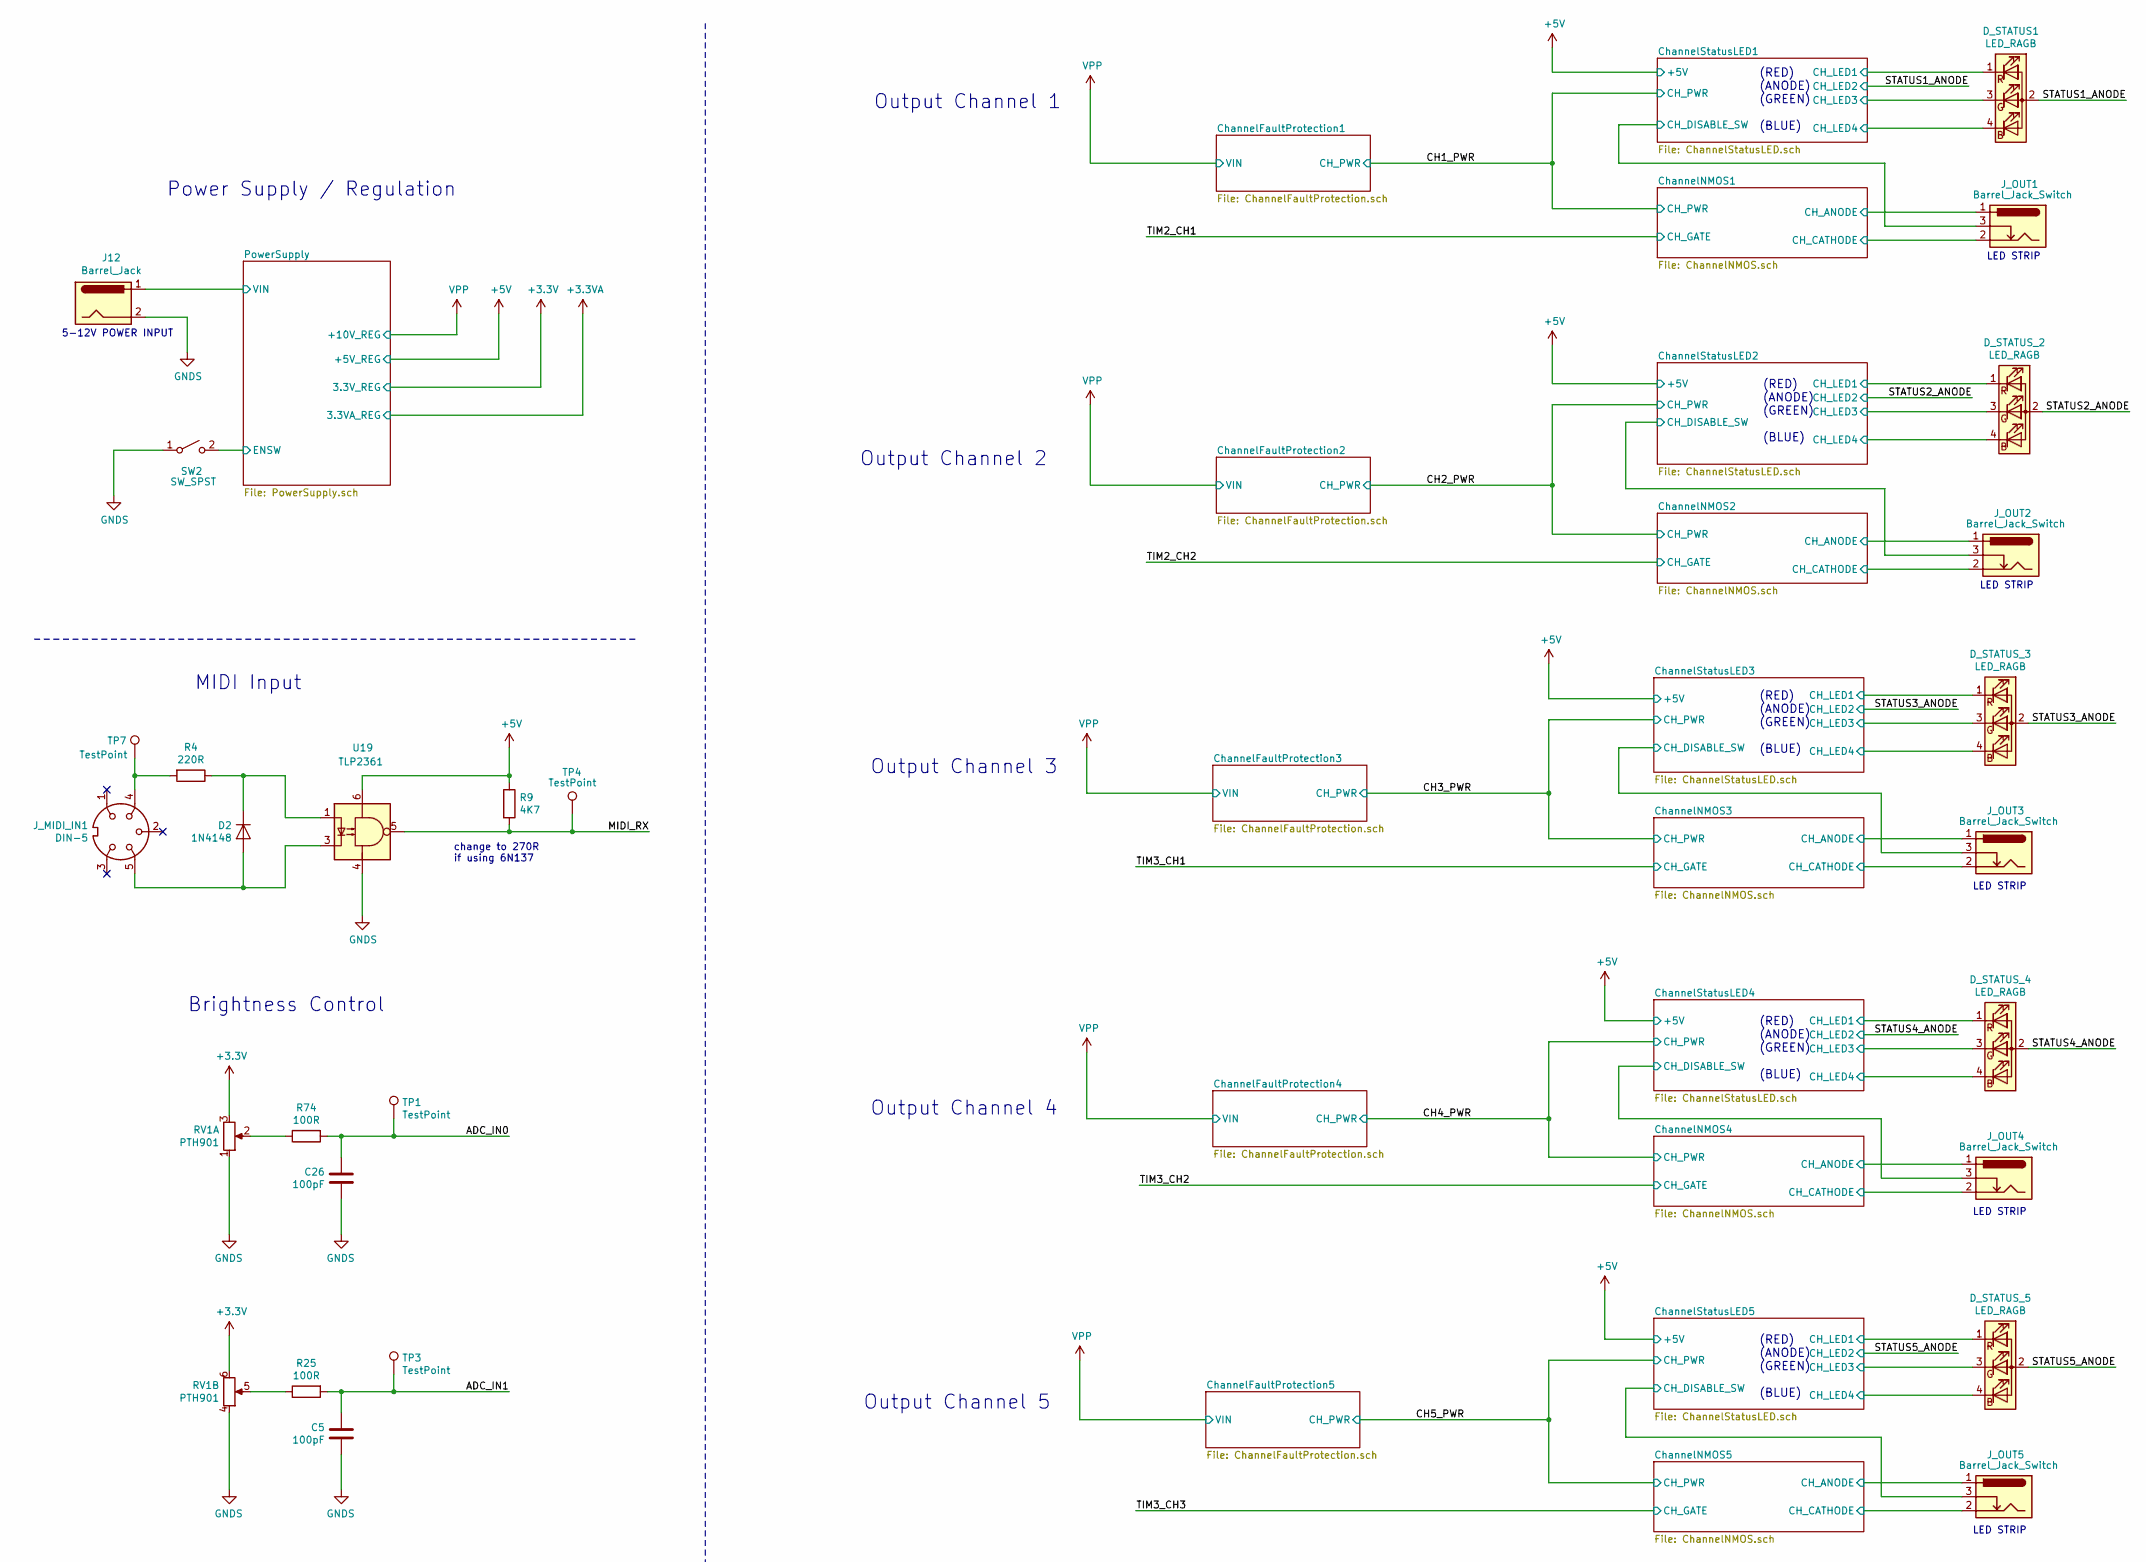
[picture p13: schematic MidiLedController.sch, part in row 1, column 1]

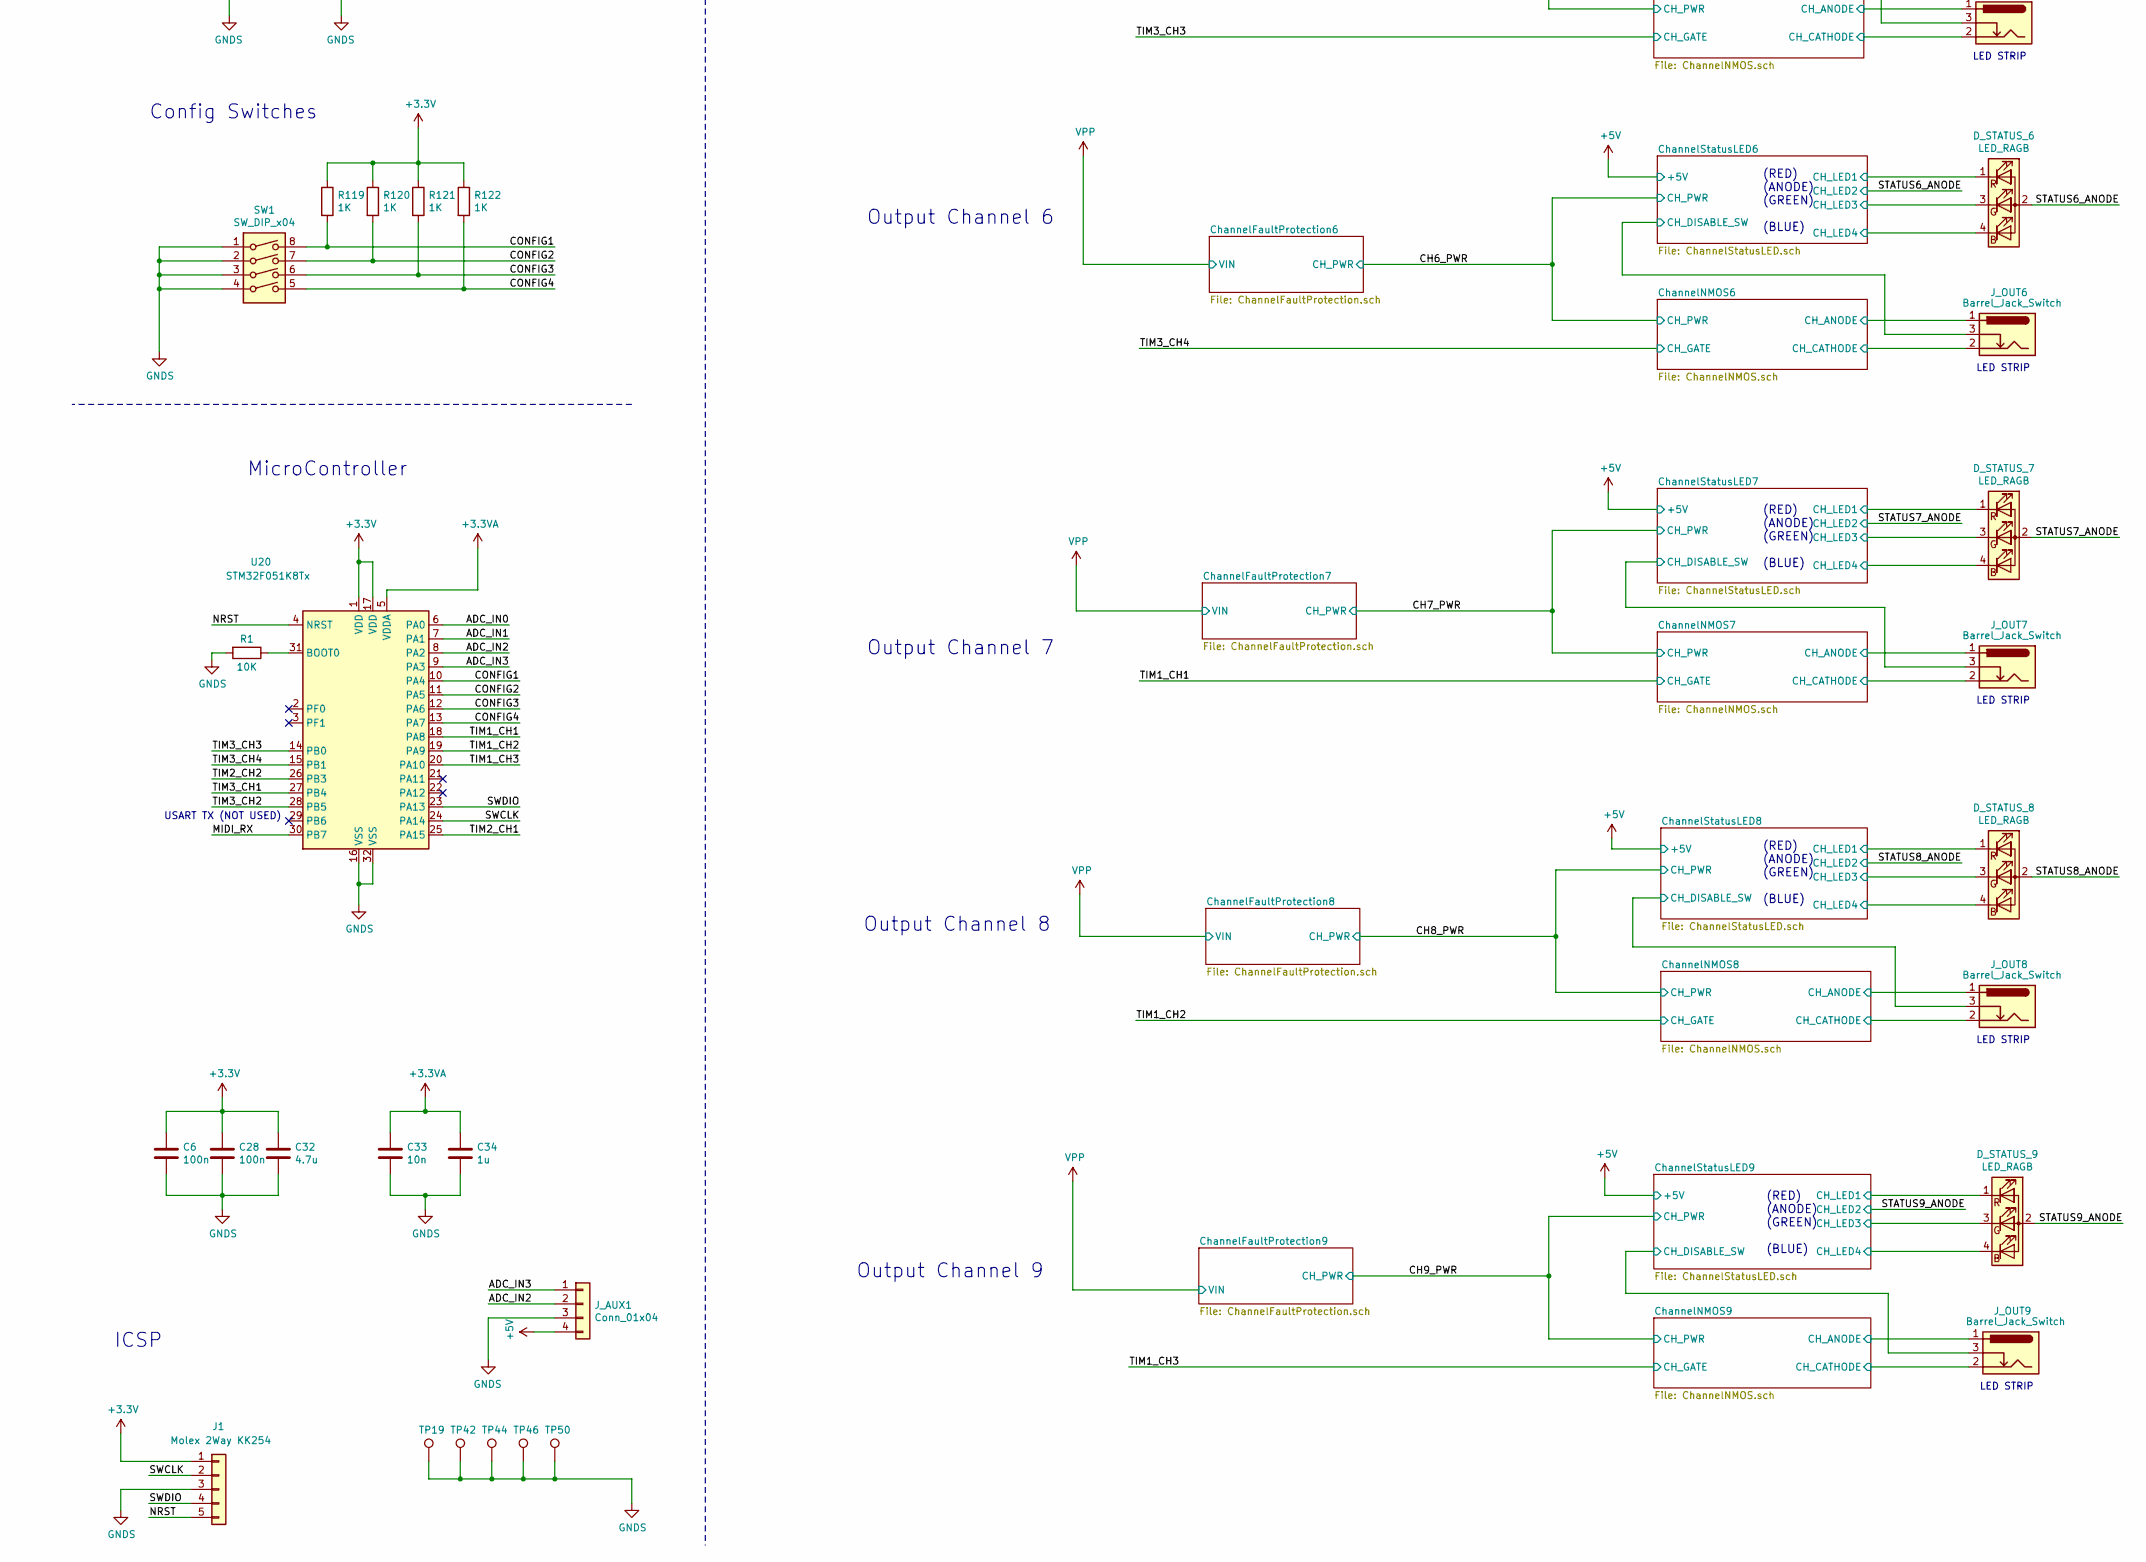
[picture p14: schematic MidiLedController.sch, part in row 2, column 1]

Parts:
C5, C26: 100pF; C_0805_2012Metric_Pad1.15x1.40mm_HandSolder; LcscNo C152892
C6, C28: 100n; C_0805_2012Metric_Pad1.15x1.40mm_HandSolder; LcscNo C94108
C32: 4.7u; C_0805_2012Metric_Pad1.15x1.40mm_HandSolder; LcscNo C87998
C33: 10n; C_0805_2012Metric_Pad1.15x1.40mm_HandSolder; LcscNo C107135
C34: 1u; C_0805_2012Metric_Pad1.15x1.40mm_HandSolder; LcscNo C376927
D2: 1N4148; D_SOD-323_HandSoldering; MouserNo 583-FM4005-T
D_STATUS1: LED_RAGB; LED_D5.0mm-4_RGB_Wide_Pins
D_STATUS_2, D_STATUS_3, D_STATUS_4, D_STATUS_5, D_STATUS_6, D_STATUS_7, D_STATUS_8, D_STATUS_9: LED_RAGB; LED_D5.0mm-4_RGB_Wide_Pins
J1: Molex 2Way KK254; PinHeader_1x05_P2.54mm_Vertical
J12: Barrel_Jack; BarrelJack_Horizontal
J_AUX1: Conn_01x04; PinHeader_1x04_P2.54mm_Vertical
J_MIDI_IN1: DIN-5; RS_5P180_DIN5_SOCKET_WSHIELD
J_OUT1, J_OUT2, J_OUT3, J_OUT4, J_OUT5, J_OUT6, J_OUT7, J_OUT8, J_OUT9: Barrel_Jack_Switch; BarrelJack_Horizontal
R1: 10K; R_0805_2012Metric_Pad1.15x1.40mm_HandSolder; LcscNo C115295
R4: 220R; R_0805_2012Metric_Pad1.15x1.40mm_HandSolder; MouserNo 71-CRCW0805220RFKEAC
R9: 4K7; R_0805_2012Metric_Pad1.15x1.40mm_HandSolder; MouserNo 279-CRGP0805F270R
R25, R74: 100R; R_0805_2012Metric_Pad1.15x1.40mm_HandSolder; LcscNo C106949
R119, R120, R121, R122: 1K; R_0805_2012Metric_Pad1.15x1.40mm_HandSolder; LcscNo C25623
RV1: PTH901; MouserNo 652-PTH901-030S-103B
SW1: SW_DIP_x04; SW_DIP_SPSTx04_Slide_6.7x11.72mm_W7.62mm_P2.54mm_LowProfile
SW2: SW_SPST; SW_Tactile_SPST_Angled_PTS645Vx31-2LFS
TP1, TP3, TP4, TP7, TP19, TP42, TP44, TP46, TP50: TestPoint; TestPoint_Pad_1.0x1.0mm
U19: TLP2361; SO-6_4.4x3.6mm_P1.27mm
U20: STM32F051K8Tx; LQFP-32_7x7mm_P0.8mm; MouserNo 511-STM32F051K8T6

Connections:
+3.3VA: C33.1, C34.1, U20.5 (VDDA); also elsewhere on the board
+3V3: C6.1, C28.1, C32.1, J1.1, R119.1, R120.1, R121.1, R122.1, RV1.3, RV1.6, U20.1 (VDD), U20.17 (VDD); also elsewhere on the board
+5V: J_AUX1.4, R9.1, U19.6; also elsewhere on the board
/ADC_IN0: C26.2, R74.2, TP1.1, U20.6 (PA0)
/ADC_IN1: C5.2, R25.2, TP3.1, U20.7 (PA1)
/ADC_IN2: J_AUX1.2, U20.8 (PA2)
/ADC_IN3: J_AUX1.1, U20.9 (PA3)
/CH1_PWR: J_OUT1.1; also elsewhere on the board
/CH2_PWR: J_OUT2.1; also elsewhere on the board
/CH3_PWR: J_OUT3.1; also elsewhere on the board
/CH4_PWR: J_OUT4.1; also elsewhere on the board
/CH5_PWR: J_OUT5.1; also elsewhere on the board
/CH6_PWR: J_OUT6.1; also elsewhere on the board
/CH7_PWR: J_OUT7.1; also elsewhere on the board
/CH8_PWR: J_OUT8.1; also elsewhere on the board
/CH9_PWR: J_OUT9.1; also elsewhere on the board
/CONFIG1: R119.2, SW1.8, U20.10 (PA4)
/CONFIG2: R120.2, SW1.7, U20.11 (PA5)
/CONFIG3: R121.2, SW1.6, U20.12 (PA6)
/CONFIG4: R122.2, SW1.5, U20.13 (PA7)
/ChannelNMOS1/CH_CATHODE: J_OUT1.2; also elsewhere on the board
/ChannelNMOS2/CH_CATHODE: J_OUT2.2; also elsewhere on the board
/ChannelNMOS3/CH_CATHODE: J_OUT3.2; also elsewhere on the board
/ChannelNMOS4/CH_CATHODE: J_OUT4.2; also elsewhere on the board
/ChannelNMOS5/CH_CATHODE: J_OUT5.2; also elsewhere on the board
/ChannelNMOS6/CH_CATHODE: J_OUT6.2; also elsewhere on the board
/ChannelNMOS7/CH_CATHODE: J_OUT7.2; also elsewhere on the board
/ChannelNMOS8/CH_CATHODE: J_OUT8.2; also elsewhere on the board
/ChannelNMOS9/CH_CATHODE: J_OUT9.2; also elsewhere on the board
/ChannelStatusLED1/CH_DISABLE_SW: J_OUT1.3; also elsewhere on the board
/ChannelStatusLED1/CH_LED1: D_STATUS1.1 (RK); also elsewhere on the board
/ChannelStatusLED1/CH_LED3: D_STATUS1.3 (GK); also elsewhere on the board
/ChannelStatusLED1/CH_LED4: D_STATUS1.4 (BK); also elsewhere on the board
/ChannelStatusLED2/CH_DISABLE_SW: J_OUT2.3; also elsewhere on the board
/ChannelStatusLED2/CH_LED1: D_STATUS_2.1 (RK); also elsewhere on the board
/ChannelStatusLED2/CH_LED3: D_STATUS_2.3 (GK); also elsewhere on the board
/ChannelStatusLED2/CH_LED4: D_STATUS_2.4 (BK); also elsewhere on the board
/ChannelStatusLED3/CH_DISABLE_SW: J_OUT3.3; also elsewhere on the board
/ChannelStatusLED3/CH_LED1: D_STATUS_3.1 (RK); also elsewhere on the board
/ChannelStatusLED3/CH_LED3: D_STATUS_3.3 (GK); also elsewhere on the board
/ChannelStatusLED3/CH_LED4: D_STATUS_3.4 (BK); also elsewhere on the board
/ChannelStatusLED4/CH_DISABLE_SW: J_OUT4.3; also elsewhere on the board
/ChannelStatusLED4/CH_LED1: D_STATUS_4.1 (RK); also elsewhere on the board
/ChannelStatusLED4/CH_LED3: D_STATUS_4.3 (GK); also elsewhere on the board
/ChannelStatusLED4/CH_LED4: D_STATUS_4.4 (BK); also elsewhere on the board
/ChannelStatusLED5/CH_DISABLE_SW: J_OUT5.3; also elsewhere on the board
/ChannelStatusLED5/CH_LED1: D_STATUS_5.1 (RK); also elsewhere on the board
/ChannelStatusLED5/CH_LED3: D_STATUS_5.3 (GK); also elsewhere on the board
/ChannelStatusLED5/CH_LED4: D_STATUS_5.4 (BK); also elsewhere on the board
/ChannelStatusLED6/CH_DISABLE_SW: J_OUT6.3; also elsewhere on the board
/ChannelStatusLED6/CH_LED1: D_STATUS_6.1 (RK); also elsewhere on the board
/ChannelStatusLED6/CH_LED3: D_STATUS_6.3 (GK); also elsewhere on the board
/ChannelStatusLED6/CH_LED4: D_STATUS_6.4 (BK); also elsewhere on the board
/ChannelStatusLED7/CH_DISABLE_SW: J_OUT7.3; also elsewhere on the board
/ChannelStatusLED7/CH_LED1: D_STATUS_7.1 (RK); also elsewhere on the board
/ChannelStatusLED7/CH_LED3: D_STATUS_7.3 (GK); also elsewhere on the board
/ChannelStatusLED7/CH_LED4: D_STATUS_7.4 (BK); also elsewhere on the board
/ChannelStatusLED8/CH_DISABLE_SW: J_OUT8.3; also elsewhere on the board
/ChannelStatusLED8/CH_LED1: D_STATUS_8.1 (RK); also elsewhere on the board
/ChannelStatusLED8/CH_LED3: D_STATUS_8.3 (GK); also elsewhere on the board
/ChannelStatusLED8/CH_LED4: D_STATUS_8.4 (BK); also elsewhere on the board
/ChannelStatusLED9/CH_DISABLE_SW: J_OUT9.3; also elsewhere on the board
/ChannelStatusLED9/CH_LED1: D_STATUS_9.1 (RK); also elsewhere on the board
/ChannelStatusLED9/CH_LED3: D_STATUS_9.3 (GK); also elsewhere on the board
/ChannelStatusLED9/CH_LED4: D_STATUS_9.4 (BK); also elsewhere on the board
/MIDI_RX: R9.2, TP4.1, U19.5, U20.30 (PB7)
/NRST: J1.5, U20.4 (NRST)
/PowerSupply/ENSW: SW2.2 (B); also elsewhere on the board
/PowerSupply/VIN: J12.1; also elsewhere on the board
/STATUS1_ANODE: D_STATUS1.2 (A); also elsewhere on the board
/STATUS2_ANODE: D_STATUS_2.2 (A); also elsewhere on the board
/STATUS3_ANODE: D_STATUS_3.2 (A); also elsewhere on the board
/STATUS4_ANODE: D_STATUS_4.2 (A); also elsewhere on the board
/STATUS5_ANODE: D_STATUS_5.2 (A); also elsewhere on the board
/STATUS6_ANODE: D_STATUS_6.2 (A); also elsewhere on the board
/STATUS7_ANODE: D_STATUS_7.2 (A); also elsewhere on the board
/STATUS8_ANODE: D_STATUS_8.2 (A); also elsewhere on the board
/STATUS9_ANODE: D_STATUS_9.2 (A); also elsewhere on the board
/SWCLK: J1.2, U20.24 (PA14)
/SWDIO: J1.4, U20.23 (PA13)
/TIM1_CH1: U20.18 (PA8); also elsewhere on the board
/TIM1_CH2: U20.19 (PA9); also elsewhere on the board
/TIM1_CH3: U20.20 (PA10); also elsewhere on the board
/TIM2_CH1: U20.25 (PA15); also elsewhere on the board
/TIM2_CH2: U20.26 (PB3); also elsewhere on the board
/TIM3_CH1: U20.27 (PB4); also elsewhere on the board
/TIM3_CH2: U20.28 (PB5); also elsewhere on the board
/TIM3_CH3: U20.14 (PB0); also elsewhere on the board
/TIM3_CH4: U20.15 (PB1); also elsewhere on the board
GNDS: C5.1, C6.2, C26.1, C28.2, C32.2, C33.2, C34.2, J1.3, J12.2, J_AUX1.3, R1.2, RV1.1, RV1.4, SW1.1, SW1.2, SW1.3, SW1.4, SW2.1 (A), TP19.1, TP42.1, TP44.1, TP46.1, TP50.1, U19.4, U20.16 (VSS), U20.32 (VSS); also elsewhere on the board
unnamed: D2.1 (K), R4.1, U19.1
unnamed: D2.2 (A), J_MIDI_IN1.5, U19.3
unnamed: J_MIDI_IN1.4, R4.2, TP7.1
unnamed: R1.1, U20.31 (BOOT0)
unnamed: R25.1, RV1.5
unnamed: R74.1, RV1.2

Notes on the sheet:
ICSP
MicroController
USART TX (NOT USED)
MIDI Input
Power Supply / Regulation
Brightness Control
5-12V POWER INPUT
Output Channel 1
Output Channel 2
Output Channel 3
Output Channel 4
Output Channel 5
Output Channel 6
Output Channel 7
Output Channel 8
Output Channel 9
(RED) (ANODE) (GREEN) (BLUE)
LED STRIP
change to 270R if using 6N137
Config Switches

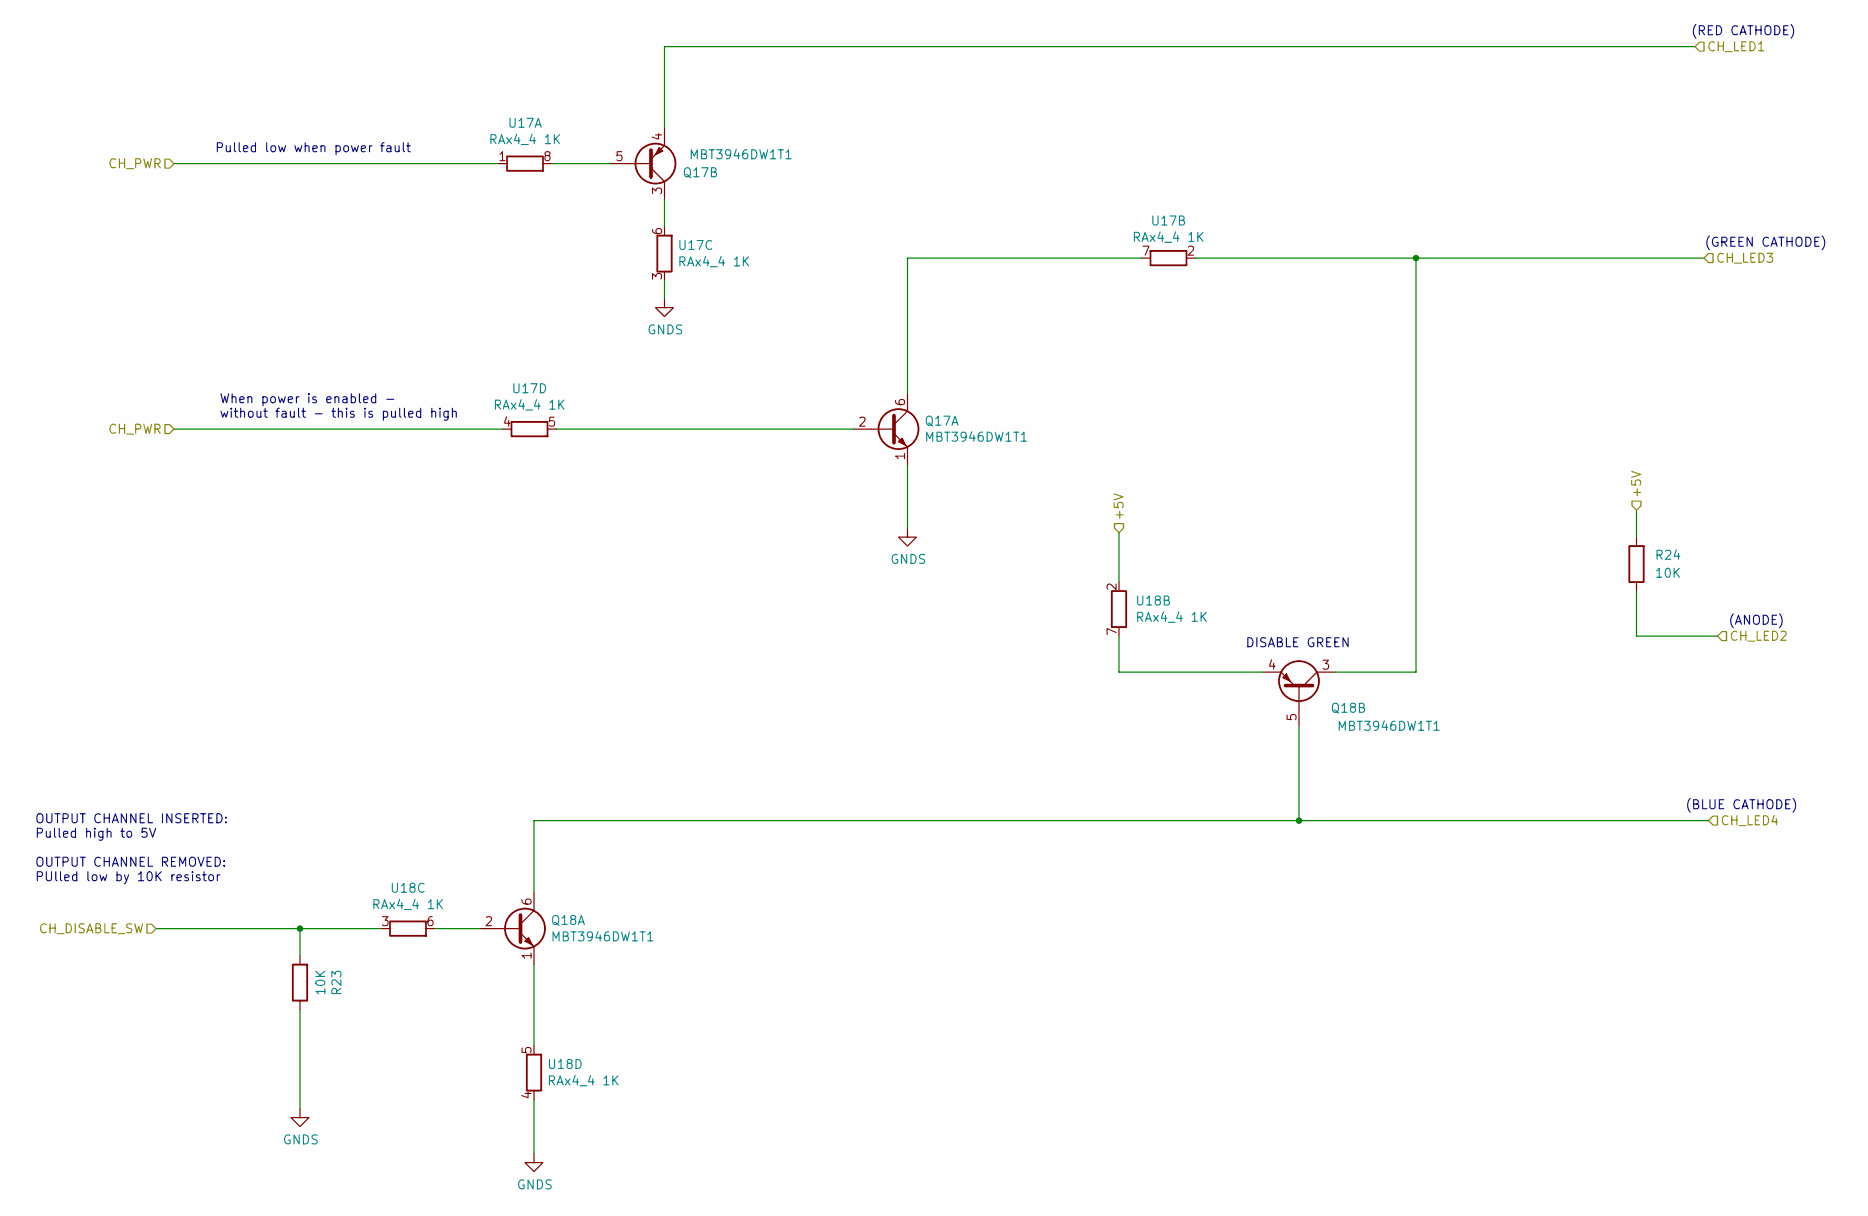
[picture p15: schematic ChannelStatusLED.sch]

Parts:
Q1, Q2: MBT3946DW1T1; SOT-363_SC-70-6
R2, R3: 10K; R_0805_2012Metric_Pad1.15x1.40mm_HandSolder; LcscNo C115295
U1, U2: RAx4_4 1K; R_Array_Convex_4x0603; LcscNo C396839

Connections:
+5V: R3.2, U2.2; also elsewhere on the board
/CH1_PWR: U1.1, U1.4; also elsewhere on the board
/ChannelStatusLED1/CH_DISABLE_SW: R2.2, U2.3; also elsewhere on the board
/ChannelStatusLED1/CH_LED1: Q1.4 (E2); also elsewhere on the board
/ChannelStatusLED1/CH_LED3: Q2.3 (C2), U1.2; also elsewhere on the board
/ChannelStatusLED1/CH_LED4: Q2.5 (B2), Q2.6 (C1); also elsewhere on the board
/STATUS1_ANODE: R3.1; also elsewhere on the board
GNDS: Q1.1 (E1), R2.1, U1.3, U2.4; also elsewhere on the board
unnamed: Q1.2 (B1), U1.5
unnamed: Q1.3 (C2), U1.6
unnamed: Q1.5 (B2), U1.8
unnamed: Q1.6 (C1), U1.7
unnamed: Q2.1 (E1), U2.5
unnamed: Q2.2 (B1), U2.6
unnamed: Q2.4 (E2), U2.7

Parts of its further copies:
Q3, Q4, Q5, Q6, Q7, Q8, Q9, Q10, Q11, Q12, Q13, Q14, Q15, Q16, Q17, Q18: MBT3946DW1T1; SOT-363_SC-70-6
R5, R6, R7, R8, R10, R11, R12, R14, R17, R18, R19, R20, R21, R22, R23, R24: 10K; R_0805_2012Metric_Pad1.15x1.40mm_HandSolder; LcscNo C115295
U3, U4, U5, U6, U7, U8, U9, U10, U11, U12, U13, U14, U15, U16, U17, U18: RAx4_4 1K; R_Array_Convex_4x0603; LcscNo C396839

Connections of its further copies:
+5V: R6.2, R8.2, R11.2, R14.2, R18.2, R20.2, R22.2, R24.2, U4.1, U4.2, U6.1, U6.2, U8.1, U8.2, U10.1, U10.2, U12.1, U12.2, U14.1, U14.2, U16.1, U16.2, U18.1, U18.2; also elsewhere on the board
/CH2_PWR: U3.1, U3.4; also elsewhere on the board
/CH3_PWR: U5.1, U5.4; also elsewhere on the board
/CH4_PWR: U7.1, U7.4; also elsewhere on the board
/CH5_PWR: U9.1, U9.4; also elsewhere on the board
/CH6_PWR: U11.1, U11.4; also elsewhere on the board
/CH7_PWR: U13.1, U13.4; also elsewhere on the board
/CH8_PWR: U15.1, U15.4; also elsewhere on the board
/CH9_PWR: U17.1, U17.4; also elsewhere on the board
/ChannelNMOS2/CH_CATHODE: U4.8; also elsewhere on the board
/ChannelNMOS3/CH_CATHODE: U6.8; also elsewhere on the board
/ChannelNMOS4/CH_CATHODE: U8.8; also elsewhere on the board
/ChannelNMOS5/CH_CATHODE: U10.8; also elsewhere on the board
/ChannelNMOS6/CH_CATHODE: U12.8; also elsewhere on the board
/ChannelNMOS7/CH_CATHODE: U14.8; also elsewhere on the board
/ChannelNMOS8/CH_CATHODE: U16.8; also elsewhere on the board
/ChannelNMOS9/CH_CATHODE: U18.8; also elsewhere on the board
/ChannelStatusLED2/CH_DISABLE_SW: R5.2, U4.3; also elsewhere on the board
/ChannelStatusLED2/CH_LED1: Q3.4 (E2); also elsewhere on the board
/ChannelStatusLED2/CH_LED3: Q4.3 (C2), U3.2; also elsewhere on the board
/ChannelStatusLED2/CH_LED4: Q4.5 (B2), Q4.6 (C1); also elsewhere on the board
/ChannelStatusLED3/CH_DISABLE_SW: R7.2, U6.3; also elsewhere on the board
/ChannelStatusLED3/CH_LED1: Q5.4 (E2); also elsewhere on the board
/ChannelStatusLED3/CH_LED3: Q6.3 (C2), U5.2; also elsewhere on the board
/ChannelStatusLED3/CH_LED4: Q6.5 (B2), Q6.6 (C1); also elsewhere on the board
/ChannelStatusLED4/CH_DISABLE_SW: R10.2, U8.3; also elsewhere on the board
/ChannelStatusLED4/CH_LED1: Q7.4 (E2); also elsewhere on the board
/ChannelStatusLED4/CH_LED3: Q8.3 (C2), U7.2; also elsewhere on the board
/ChannelStatusLED4/CH_LED4: Q8.5 (B2), Q8.6 (C1); also elsewhere on the board
/ChannelStatusLED5/CH_DISABLE_SW: R12.2, U10.3; also elsewhere on the board
/ChannelStatusLED5/CH_LED1: Q9.4 (E2); also elsewhere on the board
/ChannelStatusLED5/CH_LED3: Q10.3 (C2), U9.2; also elsewhere on the board
/ChannelStatusLED5/CH_LED4: Q10.5 (B2), Q10.6 (C1); also elsewhere on the board
/ChannelStatusLED6/CH_DISABLE_SW: R17.2, U12.3; also elsewhere on the board
/ChannelStatusLED6/CH_LED1: Q11.4 (E2); also elsewhere on the board
/ChannelStatusLED6/CH_LED3: Q12.3 (C2), U11.2; also elsewhere on the board
/ChannelStatusLED6/CH_LED4: Q12.5 (B2), Q12.6 (C1); also elsewhere on the board
/ChannelStatusLED7/CH_DISABLE_SW: R19.2, U14.3; also elsewhere on the board
/ChannelStatusLED7/CH_LED1: Q13.4 (E2); also elsewhere on the board
/ChannelStatusLED7/CH_LED3: Q14.3 (C2), U13.2; also elsewhere on the board
/ChannelStatusLED7/CH_LED4: Q14.5 (B2), Q14.6 (C1); also elsewhere on the board
/ChannelStatusLED8/CH_DISABLE_SW: R21.2, U16.3; also elsewhere on the board
/ChannelStatusLED8/CH_LED1: Q15.4 (E2); also elsewhere on the board
/ChannelStatusLED8/CH_LED3: Q16.3 (C2), U15.2; also elsewhere on the board
/ChannelStatusLED8/CH_LED4: Q16.5 (B2), Q16.6 (C1); also elsewhere on the board
/ChannelStatusLED9/CH_DISABLE_SW: R23.2, U18.3; also elsewhere on the board
/ChannelStatusLED9/CH_LED1: Q17.4 (E2); also elsewhere on the board
/ChannelStatusLED9/CH_LED3: Q18.3 (C2), U17.2; also elsewhere on the board
/ChannelStatusLED9/CH_LED4: Q18.5 (B2), Q18.6 (C1); also elsewhere on the board
/STATUS2_ANODE: R6.1; also elsewhere on the board
/STATUS3_ANODE: R8.1; also elsewhere on the board
/STATUS4_ANODE: R11.1; also elsewhere on the board
/STATUS5_ANODE: R14.1; also elsewhere on the board
/STATUS6_ANODE: R18.1; also elsewhere on the board
/STATUS7_ANODE: R20.1; also elsewhere on the board
/STATUS8_ANODE: R22.1; also elsewhere on the board
/STATUS9_ANODE: R24.1; also elsewhere on the board
GNDS: Q3.1 (E1), Q5.1 (E1), Q7.1 (E1), Q9.1 (E1), Q11.1 (E1), Q13.1 (E1), Q15.1 (E1), Q17.1 (E1), R5.1, R7.1, R10.1, R12.1, R17.1, R19.1, R21.1, R23.1, U3.3, U4.4, U5.3, U6.4, U7.3, U8.4, U9.3, U10.4, U11.3, U12.4, U13.3, U14.4, U15.3, U16.4, U17.3, U18.4; also elsewhere on the board
unnamed: Q3.2 (B1), U3.5
unnamed: Q3.3 (C2), U3.6
unnamed: Q3.5 (B2), U3.8
unnamed: Q3.6 (C1), U3.7
unnamed: Q4.1 (E1), U4.5
unnamed: Q4.2 (B1), U4.6
unnamed: Q4.4 (E2), U4.7
unnamed: Q5.2 (B1), U5.5
unnamed: Q5.3 (C2), U5.6
unnamed: Q5.5 (B2), U5.8
unnamed: Q5.6 (C1), U5.7
unnamed: Q6.1 (E1), U6.5
unnamed: Q6.2 (B1), U6.6
unnamed: Q6.4 (E2), U6.7
unnamed: Q7.2 (B1), U7.5
unnamed: Q7.3 (C2), U7.6
unnamed: Q7.5 (B2), U7.8
unnamed: Q7.6 (C1), U7.7
unnamed: Q8.1 (E1), U8.5
unnamed: Q8.2 (B1), U8.6
unnamed: Q8.4 (E2), U8.7
unnamed: Q9.2 (B1), U9.5
unnamed: Q9.3 (C2), U9.6
unnamed: Q9.5 (B2), U9.8
unnamed: Q9.6 (C1), U9.7
unnamed: Q10.1 (E1), U10.5
unnamed: Q10.2 (B1), U10.6
unnamed: Q10.4 (E2), U10.7
unnamed: Q11.2 (B1), U11.5
unnamed: Q11.3 (C2), U11.6
unnamed: Q11.5 (B2), U11.8
unnamed: Q11.6 (C1), U11.7
unnamed: Q12.1 (E1), U12.5
unnamed: Q12.2 (B1), U12.6
unnamed: Q12.4 (E2), U12.7
unnamed: Q13.2 (B1), U13.5
unnamed: Q13.3 (C2), U13.6
unnamed: Q13.5 (B2), U13.8
unnamed: Q13.6 (C1), U13.7
unnamed: Q14.1 (E1), U14.5
unnamed: Q14.2 (B1), U14.6
unnamed: Q14.4 (E2), U14.7
unnamed: Q15.2 (B1), U15.5
unnamed: Q15.3 (C2), U15.6
unnamed: Q15.5 (B2), U15.8
unnamed: Q15.6 (C1), U15.7
unnamed: Q16.1 (E1), U16.5
unnamed: Q16.2 (B1), U16.6
unnamed: Q16.4 (E2), U16.7
unnamed: Q17.2 (B1), U17.5
unnamed: Q17.3 (C2), U17.6
unnamed: Q17.5 (B2), U17.8
unnamed: Q17.6 (C1), U17.7
unnamed: Q18.1 (E1), U18.5
unnamed: Q18.2 (B1), U18.6
unnamed: Q18.4 (E2), U18.7

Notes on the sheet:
When power is enabled - without fault - this is pulled high
(BLUE CATHODE)
(ANODE)
(GREEN CATHODE)
Pulled low when power fault
(RED CATHODE)
DISABLE GREEN
OUTPUT CHANNEL INSERTED: Pulled high to 5V OUTPUT CHANNEL REMOVED: PUlled low by 10K resistor

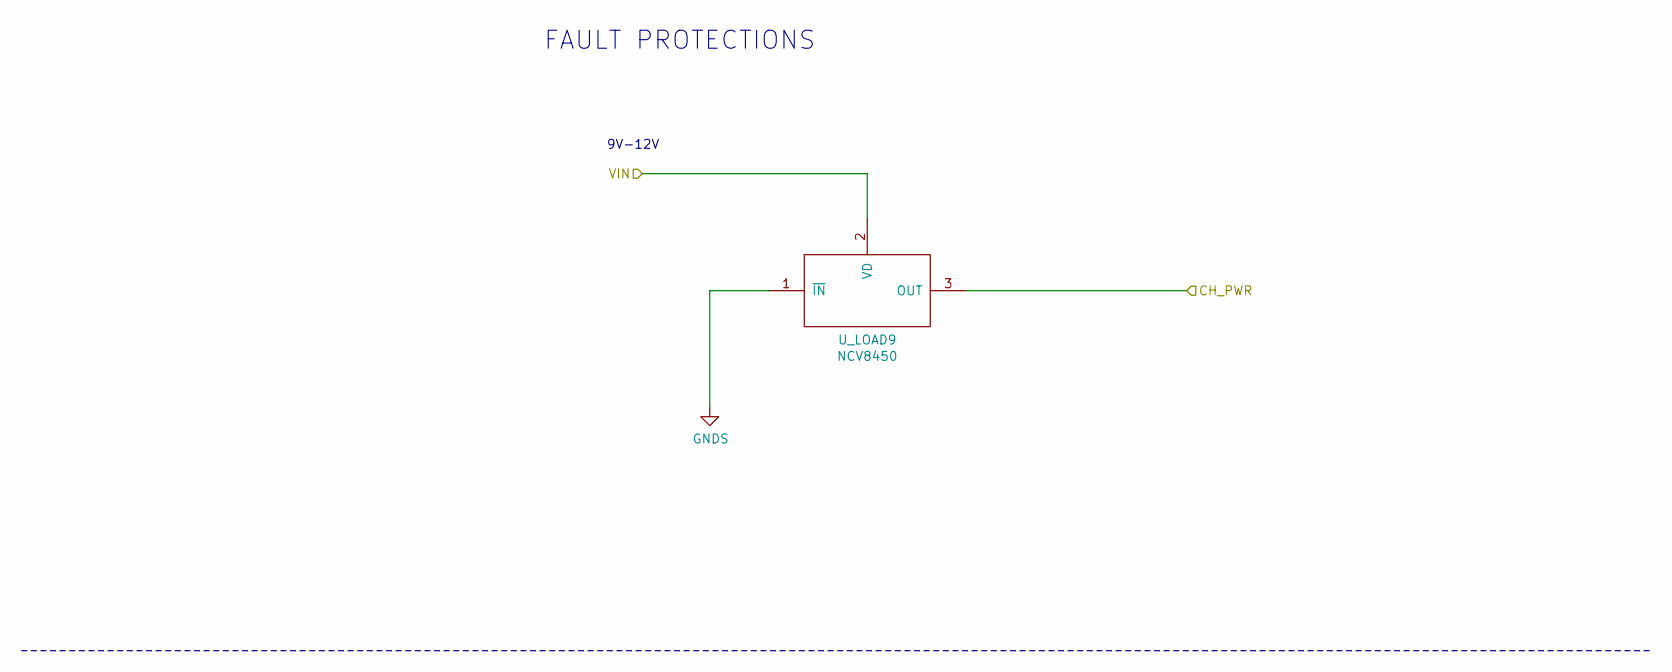
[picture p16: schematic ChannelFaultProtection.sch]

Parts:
U_LOAD2: NCV8450; SOT-223-3_TabPin2; LcscNo C100028

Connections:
/CH2_PWR: U_LOAD2.3 (OUT); also elsewhere on the board
GNDS: U_LOAD2.1 (~IN); also elsewhere on the board
VPP: U_LOAD2.2 (VD); also elsewhere on the board

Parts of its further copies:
U_LOAD1, U_LOAD3, U_LOAD4, U_LOAD5, U_LOAD6, U_LOAD7, U_LOAD8, U_LOAD9: NCV8450; SOT-223-3_TabPin2; LcscNo C100028

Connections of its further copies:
/CH1_PWR: U_LOAD1.3 (OUT); also elsewhere on the board
/CH3_PWR: U_LOAD3.3 (OUT); also elsewhere on the board
/CH4_PWR: U_LOAD4.3 (OUT); also elsewhere on the board
/CH5_PWR: U_LOAD5.3 (OUT); also elsewhere on the board
/CH6_PWR: U_LOAD6.3 (OUT); also elsewhere on the board
/CH7_PWR: U_LOAD7.3 (OUT); also elsewhere on the board
/CH8_PWR: U_LOAD8.3 (OUT); also elsewhere on the board
/CH9_PWR: U_LOAD9.3 (OUT); also elsewhere on the board
GNDS: U_LOAD1.1 (~IN), U_LOAD3.1 (~IN), U_LOAD4.1 (~IN), U_LOAD5.1 (~IN), U_LOAD6.1 (~IN), U_LOAD7.1 (~IN), U_LOAD8.1 (~IN), U_LOAD9.1 (~IN); also elsewhere on the board
VPP: U_LOAD1.2 (VD), U_LOAD3.2 (VD), U_LOAD4.2 (VD), U_LOAD5.2 (VD), U_LOAD6.2 (VD), U_LOAD7.2 (VD), U_LOAD8.2 (VD), U_LOAD9.2 (VD); also elsewhere on the board

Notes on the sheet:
9V-12V
FAULT PROTECTIONS

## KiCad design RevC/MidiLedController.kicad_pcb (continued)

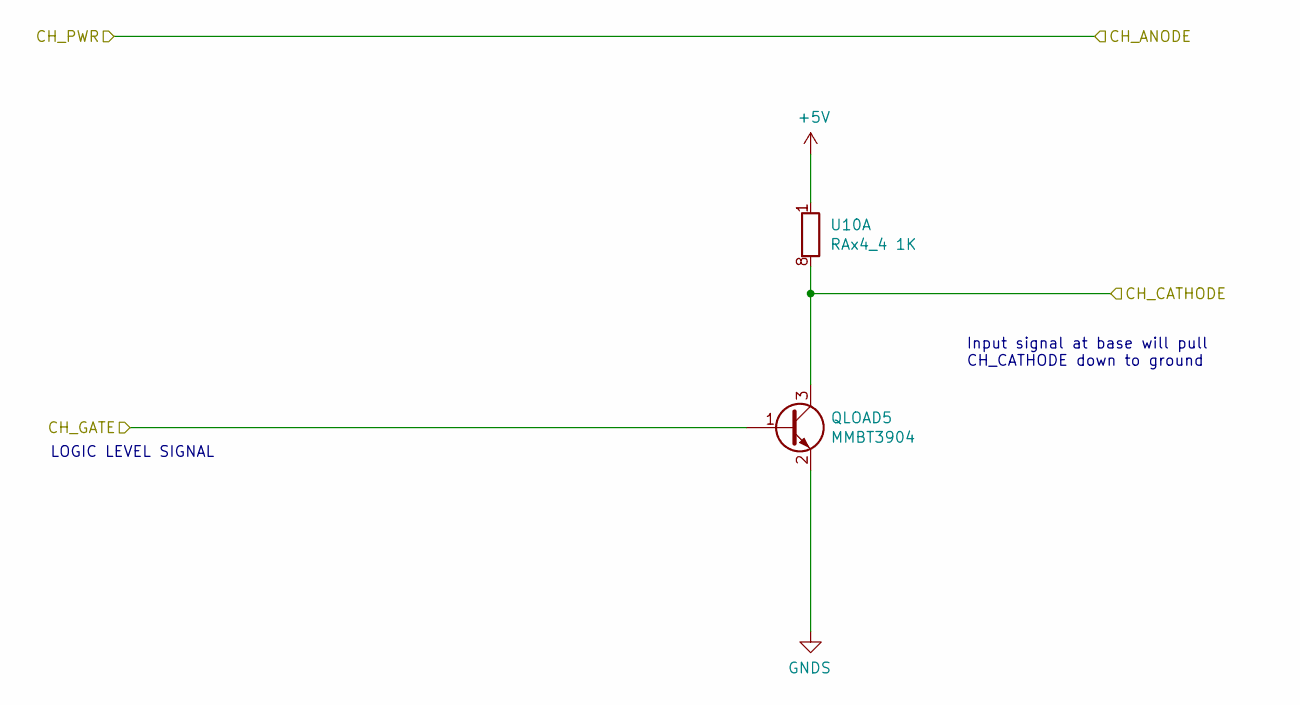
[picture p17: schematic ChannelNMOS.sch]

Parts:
QLOAD1: MMBT3904; SOT-23; LcscNo C20526
U2: RAx4_4 1K; R_Array_Convex_4x0603

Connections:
+5V: U2.1; also elsewhere on the board
/ChannelNMOS1/CH_CATHODE: QLOAD1.3 (C), U2.8; also elsewhere on the board
/TIM2_CH1: QLOAD1.1 (B); also elsewhere on the board
GNDS: QLOAD1.2 (E); also elsewhere on the board

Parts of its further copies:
QLOAD2, QLOAD3, QLOAD4, QLOAD5, QLOAD6, QLOAD7, QLOAD8, QLOAD9: MMBT3904; SOT-23; LcscNo C20526
U4, U6, U8, U10, U12, U14, U16, U18: RAx4_4 1K; R_Array_Convex_4x0603

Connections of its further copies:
+5V: U4.1, U4.2, U6.1, U6.2, U8.1, U8.2, U10.1, U10.2, U12.1, U12.2, U14.1, U14.2, U16.1, U16.2, U18.1, U18.2; also elsewhere on the board
/ChannelNMOS2/CH_CATHODE: QLOAD2.3 (C), U4.8; also elsewhere on the board
/ChannelNMOS3/CH_CATHODE: QLOAD3.3 (C), U6.8; also elsewhere on the board
/ChannelNMOS4/CH_CATHODE: QLOAD4.3 (C), U8.8; also elsewhere on the board
/ChannelNMOS5/CH_CATHODE: QLOAD5.3 (C), U10.8; also elsewhere on the board
/ChannelNMOS6/CH_CATHODE: QLOAD6.3 (C), U12.8; also elsewhere on the board
/ChannelNMOS7/CH_CATHODE: QLOAD7.3 (C), U14.8; also elsewhere on the board
/ChannelNMOS8/CH_CATHODE: QLOAD8.3 (C), U16.8; also elsewhere on the board
/ChannelNMOS9/CH_CATHODE: QLOAD9.3 (C), U18.8; also elsewhere on the board
/ChannelStatusLED2/CH_DISABLE_SW: U4.3; also elsewhere on the board
/ChannelStatusLED3/CH_DISABLE_SW: U6.3; also elsewhere on the board
/ChannelStatusLED4/CH_DISABLE_SW: U8.3; also elsewhere on the board
/ChannelStatusLED5/CH_DISABLE_SW: U10.3; also elsewhere on the board
/ChannelStatusLED6/CH_DISABLE_SW: U12.3; also elsewhere on the board
/ChannelStatusLED7/CH_DISABLE_SW: U14.3; also elsewhere on the board
/ChannelStatusLED8/CH_DISABLE_SW: U16.3; also elsewhere on the board
/ChannelStatusLED9/CH_DISABLE_SW: U18.3; also elsewhere on the board
/TIM1_CH1: QLOAD7.1 (B); also elsewhere on the board
/TIM1_CH2: QLOAD8.1 (B); also elsewhere on the board
/TIM1_CH3: QLOAD9.1 (B); also elsewhere on the board
/TIM2_CH2: QLOAD2.1 (B); also elsewhere on the board
/TIM3_CH1: QLOAD3.1 (B); also elsewhere on the board
/TIM3_CH2: QLOAD4.1 (B); also elsewhere on the board
/TIM3_CH3: QLOAD5.1 (B); also elsewhere on the board
/TIM3_CH4: QLOAD6.1 (B); also elsewhere on the board
GNDS: QLOAD2.2 (E), QLOAD3.2 (E), QLOAD4.2 (E), QLOAD5.2 (E), QLOAD6.2 (E), QLOAD7.2 (E), QLOAD8.2 (E), QLOAD9.2 (E), U4.4, U6.4, U8.4, U10.4, U12.4, U14.4, U16.4, U18.4; also elsewhere on the board
unnamed 112: U4.5; also elsewhere on the board
unnamed 113: U4.6; also elsewhere on the board
unnamed 114: U4.7; also elsewhere on the board
unnamed 119: U6.5; also elsewhere on the board
unnamed 120: U6.6; also elsewhere on the board
unnamed 121: U6.7; also elsewhere on the board
unnamed 126: U8.5; also elsewhere on the board
unnamed 127: U8.6; also elsewhere on the board
unnamed 128: U8.7; also elsewhere on the board
unnamed 133: U10.5; also elsewhere on the board
unnamed 134: U10.6; also elsewhere on the board
unnamed 135: U10.7; also elsewhere on the board
unnamed 140: U12.5; also elsewhere on the board
unnamed 141: U12.6; also elsewhere on the board
unnamed 142: U12.7; also elsewhere on the board
unnamed 147: U14.5; also elsewhere on the board
unnamed 148: U14.6; also elsewhere on the board
unnamed 149: U14.7; also elsewhere on the board
unnamed 154: U16.5; also elsewhere on the board
unnamed 155: U16.6; also elsewhere on the board
unnamed 156: U16.7; also elsewhere on the board
unnamed 161: U18.5; also elsewhere on the board
unnamed 162: U18.6; also elsewhere on the board
unnamed 163: U18.7; also elsewhere on the board

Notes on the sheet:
LOGIC LEVEL SIGNAL
Input signal at base will pull CH_CATHODE down to ground

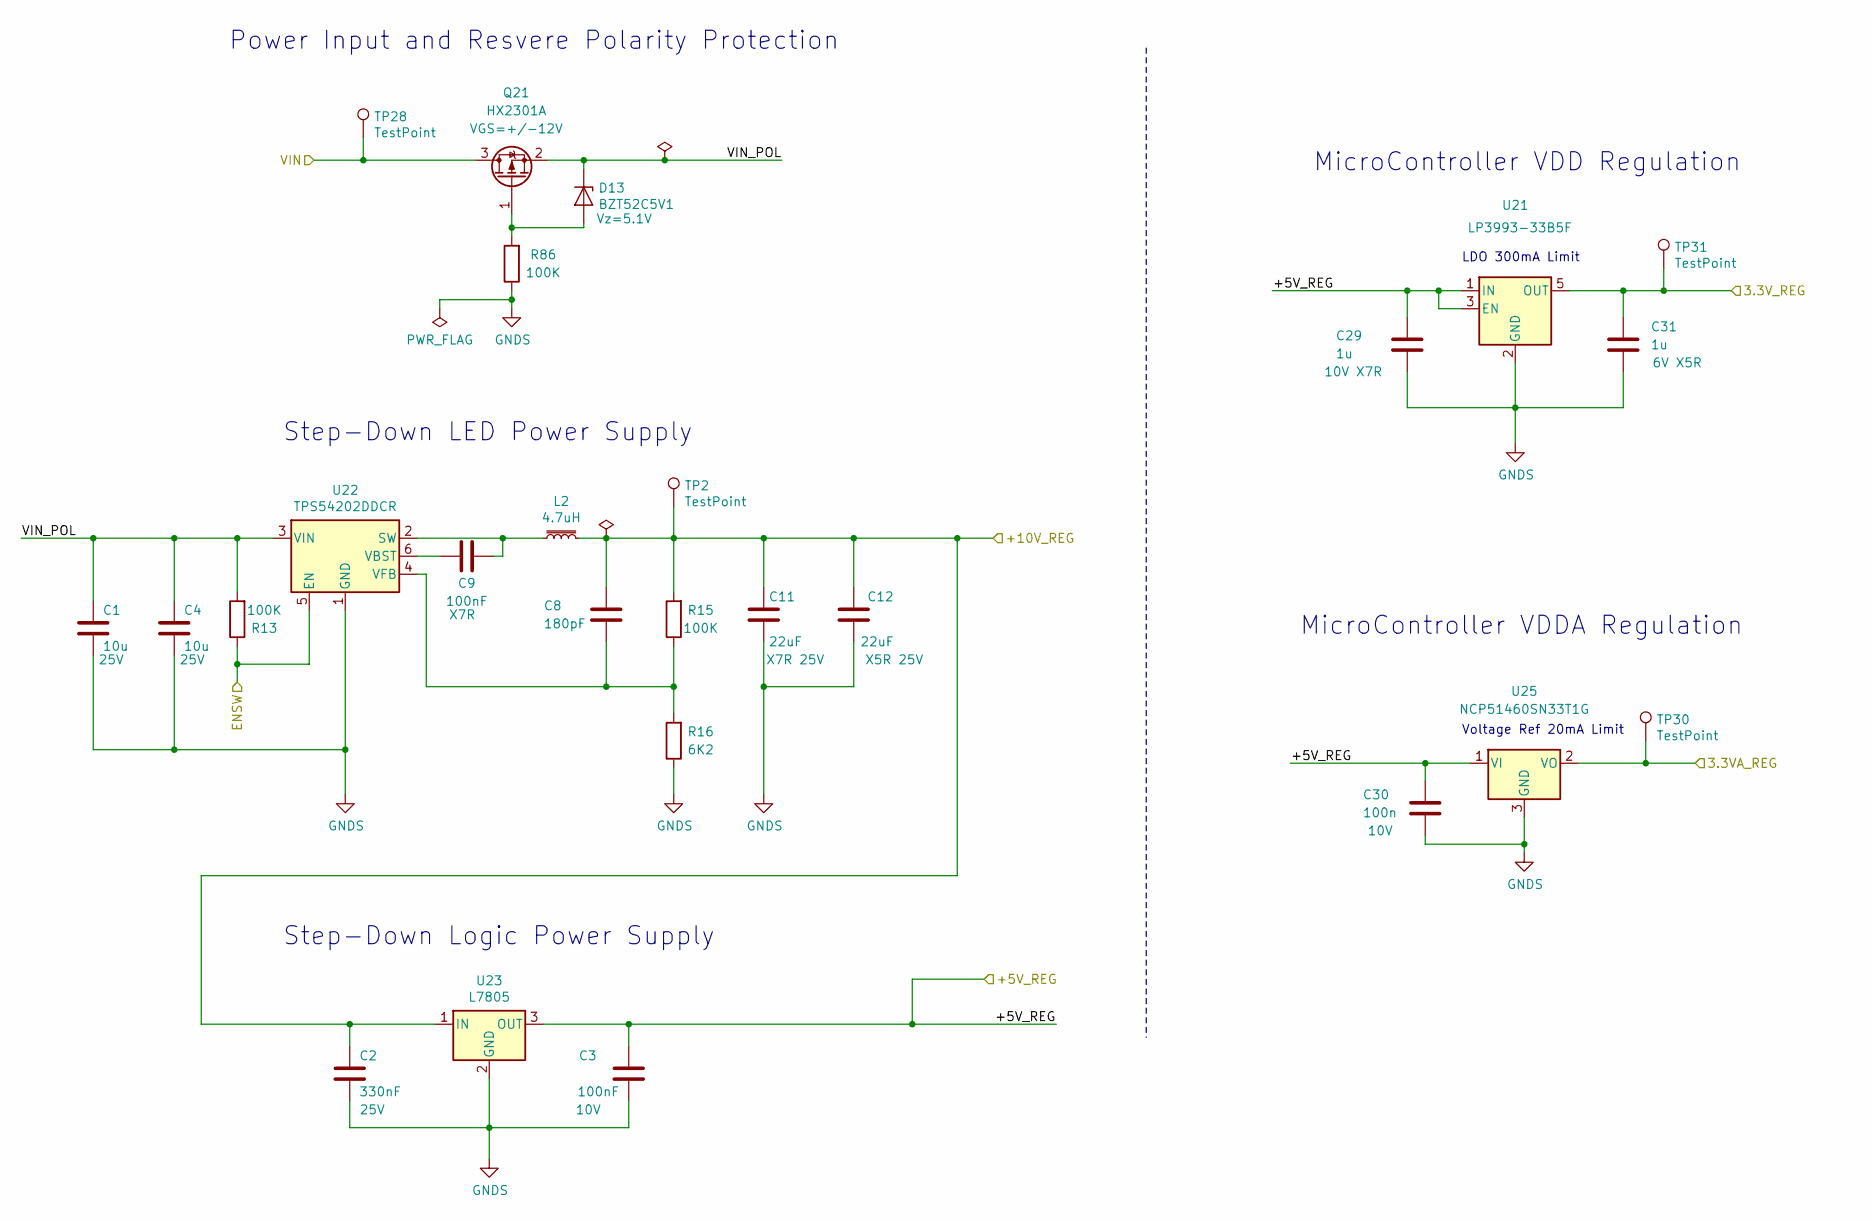
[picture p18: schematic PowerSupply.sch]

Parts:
C1, C4: 10u; C_1206_3216Metric_Pad1.42x1.75mm_HandSolder; LcscNo C14860
C2: 330nF; C_1206_3216Metric_Pad1.42x1.75mm_HandSolder; LcscNo C73142
C3: 100nF; C_1206_3216Metric_Pad1.42x1.75mm_HandSolder; LcscNo C94108
C8: 180pF; R_0805_2012Metric_Pad1.15x1.40mm_HandSolder; LcscNo C152881
C9: 100nF; R_0805_2012Metric_Pad1.15x1.40mm_HandSolder; LcscNo C94108
C11, C12: 22uF; C_1206_3216Metric_Pad1.42x1.75mm_HandSolder; LcscNo C268007
C29, C31: 1u; C_0805_2012Metric_Pad1.15x1.40mm_HandSolder; LcscNo C376927
C30: 100n; R_0805_2012Metric_Pad1.15x1.40mm_HandSolder; LcscNo C94108
D13: BZT52C5V1; D_SOD-123; LcscNo C353516
L2: 4.7uH; L_Taiyo-Yuden_NR-80xx_HandSoldering; LcscNo C266428
Q21: HX2301A; SOT-23; LcscNo C296298
R13, R15: 100K; R_0805_2012Metric_Pad1.15x1.40mm_HandSolder; LcscNo C118844
R16: 6K2; R_0805_2012Metric_Pad1.15x1.40mm_HandSolder; MouserNo 71-CRCW080510K0FKEAC
R86: 100K; R_1206_3216Metric_Pad1.42x1.75mm_HandSolder; LcscNo C118844
TP2, TP28, TP30, TP31: TestPoint; TestPoint_Pad_1.0x1.0mm
U21: LP3993-33B5F; SOT-23-5
U22: TPS54202DDCR; SOT-23-6; LcscNo C191884
U23: L7805; TO-263-2; LcscNo C15077
U25: NCP51460SN33T1G; SOT-23; MouserNo 863-NCP51460SN33T1G

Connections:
+3.3VA: TP30.1, U25.2 (VO); also elsewhere on the board
+3V3: C31.1, TP31.1, U21.5 (OUT); also elsewhere on the board
+5V: C3.1, C29.1, C30.1, U21.1 (IN), U21.3 (EN), U23.3 (OUT), U25.1 (VI); also elsewhere on the board
/PowerSupply/ENSW: R13.1, U22.5 (EN); also elsewhere on the board
/PowerSupply/VIN: Q21.3 (D), TP28.1; also elsewhere on the board
/PowerSupply/VIN_POL: C1.1, C4.1, D13.1 (K), Q21.2 (S), R13.2, U22.3 (VIN)
GNDS: C1.2, C2.2, C3.2, C4.2, C11.2, C12.2, C29.2, C30.2, C31.2, R16.1, R86.1, U21.2 (GND), U22.1 (GND), U23.2 (GND), U25.3 (GND); also elsewhere on the board
unnamed: C8.2, R15.1, R16.2, U22.4 (VFB)
unnamed: C9.1, L2.1, U22.2 (SW)
unnamed: C9.2, U22.6 (VBST)
unnamed: D13.2 (A), Q21.1 (G), R86.2
VPP: C2.1, C8.1, C11.1, C12.1, L2.2, R15.2, TP2.1, U23.1 (IN); also elsewhere on the board

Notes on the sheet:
LDO 300mA Limit
Voltage Ref 20mA Limit
Power Input and Resvere Polarity Protection
Step-Down Logic Power Supply
MicroController VDD Regulation
MicroController VDDA Regulation
Step-Down LED Power Supply

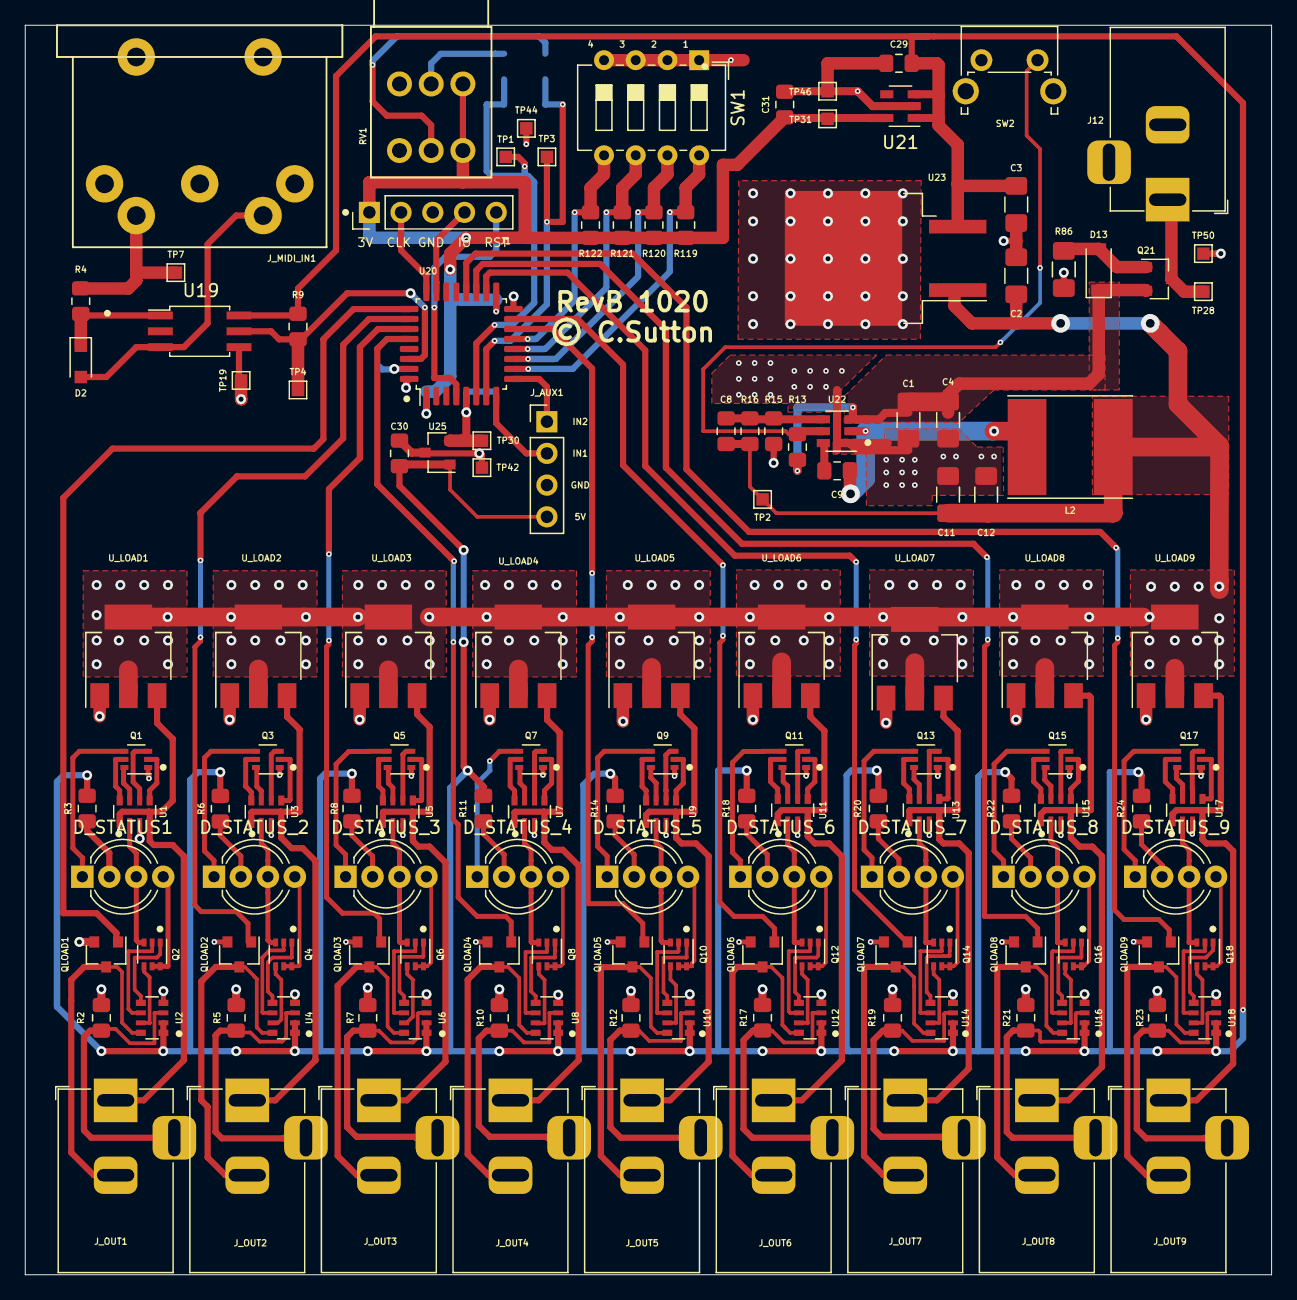
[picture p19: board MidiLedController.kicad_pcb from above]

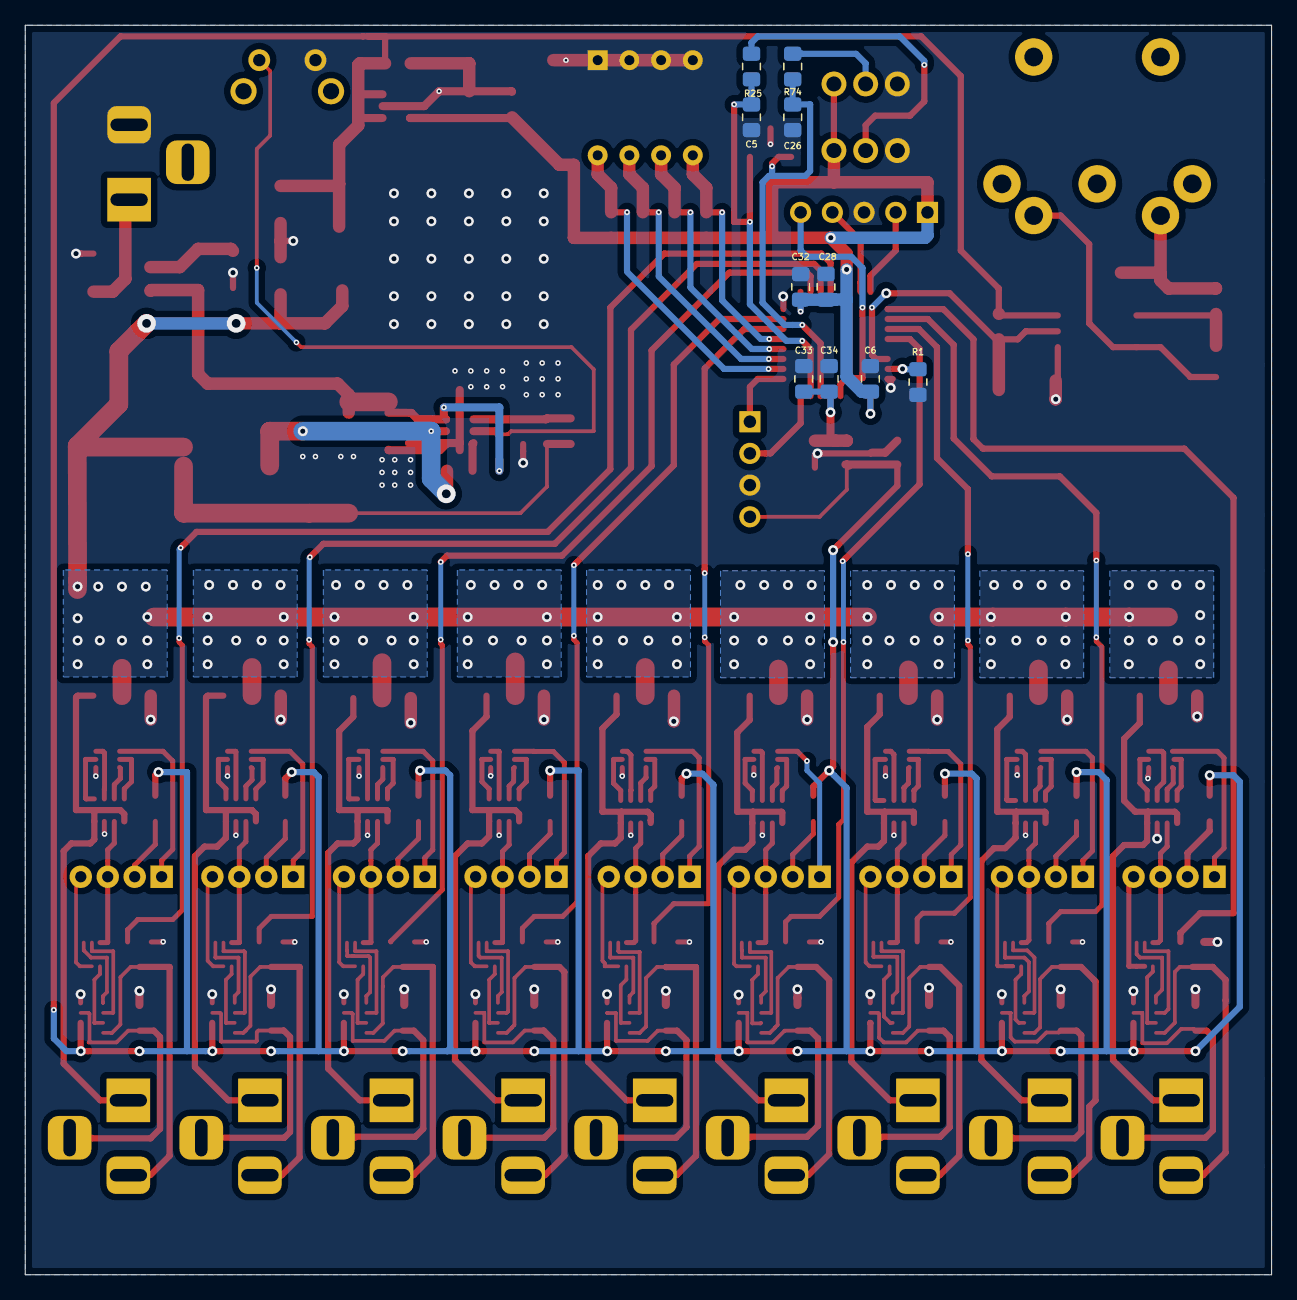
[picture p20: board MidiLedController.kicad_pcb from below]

Board: 2 copper layers, 99.8 x 100.1 mm, 151 parts (10 on the bottom side), 165 nets.

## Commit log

2019-12-28 RevA commit
    [ChannelFaultProtection.sch, ChannelNMOS.sch, ChannelStatusLED.sch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]
2019-12-30 HW
    - Added TODO list to Readme
    - Added PTH901 footprint (dual concentric pot) to lib folder
2019-12-30 HW: TPS SMPS
    - Increased VIN/GNDS trace width and included more ground vias for better thermal management
    [MidiLedController.kicad_pcb]
2020-01-16 updated HW
    changed single gang PTD901 to dual gang concentric PTH901
    [ChannelFaultProtection.sch, ChannelNMOS.sch, ChannelStatusLED.sch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]
2020-01-18 Added some annotations to schematic
    [ChannelNMOS.sch, ChannelStatusLED.sch]
2020-03-02 create revB
    [ChannelFaultProtection.sch, ChannelNMOS.sch, ChannelStatusLED.sch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]
2020-03-12 Created RevC
    Swapped LEDs for wider footprint
    [ChannelFaultProtection.sch, ChannelNMOS.sch, ChannelStatusLED.sch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]
2020-03-22 Replaced 6N135 SMDIP8 with H11L1 SMDIP6
    [ChannelFaultProtection.sch, ChannelNMOS.sch, ChannelStatusLED.sch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]
2020-03-22 Replaced H11L1 SMD6 with TLP2361 SO5
    [MidiLedController.kicad_pcb, MidiLedController.sch]
2020-03-23 hw update
    switched MCP1754 (SOT23-3) to LP3992 (SOT23-5)
    [MidiLedController.kicad_pcb, PowerSupply.sch]
2020-10-18 Added UserPots and RGB LEDS
    Updated schema docs

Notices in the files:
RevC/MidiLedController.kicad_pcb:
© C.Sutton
